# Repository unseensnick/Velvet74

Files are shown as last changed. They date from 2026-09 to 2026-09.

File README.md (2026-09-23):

# Velvet74

A 74-key split keyboard with Choc switches and a chip-down RP2040 on each half, in the Sofle layout. Key positions,
the board outline and the case come from [Ergogen](https://github.com/ergogen/ergogen); parts, nets and
fabrication data live in a KiCad 10 project aimed at JLCPCB assembly.

## The board

One 4-layer board, 268 x 118 mm before the panel rails, holds both halves 10 mm apart. Each half has 37 keys: a 6 x 5 matrix, 5 thumb
keys and 2 EC11 encoders that double as keys, each with an SK6812MINI-E under it.

- **Controller (per half):** RP2040, W25Q128JV 16 MB QSPI flash, 12 MHz ABM8-272-T3 crystal, AP2112K-3.3 LDO,
  BOOTSEL and RESET buttons.
- **USB-C host port:** 1.1 A polyfuse, B5819W reverse-current diode into +5V, SMF5.0A TVS on VBUS, USBLC6-2P6 on
  the data pair.
- **USB-C link port:** joins the halves (+5V, ground and a one-wire link on GP12), protected by its own USBLC6-2P6.
- **Display:** a 0.91" SSD1306 module on the 4-pin J3 header (I2C1).
- **Stackup:** signals on F.Cu and B.Cu, the +5V plane on In1 (with a +3.3V island under the controller), GND on
  In2. Power runs through the planes.
- **Panel:** the halves ship as one 268 x 131 mm panel. A 5 mm rail above and below carries the 2 mm tooling holes
  and three fiducials, and ten 5 mm tabs hold the halves, five per half, away from the USB-C cutouts. Mouse bites
  perforate each tab at the board edge: snap the tabs, then file the nubs flat. Nothing is left on the keyboard.

The schematic draws one half (`velvet74-half.kicad_sch`) and uses it twice, as sheets `Left` and `Right`.
Left references are plain (U1, SW10); right ones add 200 (U201, SW210). Both halves share one pin map.

## Pin map (both halves)

| Function | Pins |
| --- | --- |
| Rows 1-5, thumb row | GP5, GP4, GP3, GP2, GP1, GP0 |
| Columns outer to inner | GP29, GP28, GP27, GP26, GP25, GP24 |
| Encoder 1 (SW16) | A GP13, B GP14, key column GP20 |
| Encoder 2 (SW65) | A GP18, B GP19 |
| Display I2C1 | SDA GP6, SCL GP7 |
| RGB data | GP10, through the U6 level shifter to 5 V |
| Split link | GP12 |
| VBUS sense | GP9 (10k/10k divider) |
| Handedness jumper JP1 | GP8 (3.3 V = left, GND = right) |

37 LEDs at full white exceed the USB budget, so firmware should cap RGB brightness (around 120 of 255).

## Layout

- `velvet74.kicad_pro` / `.kicad_sch` / `.kicad_pcb` / `.kicad_dru`: the KiCad project, with the half sheet
  above.
- `lib/`: project symbols, footprints and 3D models (`my-soffle.*`), and the used JLCPCB library parts (`jlcpcb/`).
- `datasheets/`: manufacturer datasheets for every part on the board, synced from LCSC.
- `ergogen/`: the live layout (`config.yaml`). `npm run build` writes both halves' points, outline and case to
  `ergogen/output/`.
- `scripts/`: KiCad Python scripts that place parts from the Ergogen points and snap LEDs, diodes and caps to their
  switches.
- `templates/rp2040-inner-column/`: the RP2040 module the controller block started from, with its own README.
- `production/`: fabrication outputs, regenerated from the board before an order. `jlcpcb/` holds the
  Fabrication Toolkit set; `pcbway/` holds a `kicad-cli` set with a manufacturer-part-number BOM and assembly
  drawings. The two placement files use different rotation conventions, so do not mix them (see
  `production/pcbway/README.md`).

`CLAUDE.md` has the detailed file map, the rules for editing the design safely, and the checks.

## Getting started

**To open, review or edit the design** you need only [KiCad 10](https://www.kicad.org/download/) (made with
10.0.3); open `velvet74.kicad_pro`. Every library part the design uses is in the repo: the project's own parts
in `lib/my-soffle.*`, and the JLCPCB parts it uses in `lib/jlcpcb/` (copied from the JLCPCB library, MIT). The
remaining parts and 3D models are KiCad's stock ones. No Plugin and Content Manager packages, environment variables
or library setup are needed, and the 3D viewer shows every part. KiCad 8 cannot open these files; tag
`kicad8-final` is the last KiCad 8 state.

**To regenerate the layout** (key positions, outline, case): [Node.js](https://nodejs.org/) 18 or newer (Ergogen's `mathjs` dependency
requires it), then

```bash
cd ergogen && npm install && npm run build
```

Ergogen 4.2.1 is pinned in `ergogen/package.json`; the output lands in `ergogen/output/`.

**To run the scripts in `scripts/`:** KiCad's bundled Python (`<KiCad>/10.0/bin/python.exe` on Windows), with KiCad
closed. Each script's docstring says how to run it and what it overwrites.

**To regenerate `production/jlcpcb/`:** the Fabrication Toolkit plugin (from the KiCad Plugin and Content
Manager), with its automatic translation left **off**. JLCPCB's zero degrees is the part's orientation in its own
LCSC package drawing, which differs from KiCad's for some packages, so each affected part carries an
`FT Rotation Offset` or `FT Position Offset` field checked against JLC's own footprint. The plugin's name-matching
rules would rotate parts that are already right.

**To regenerate `production/pcbway/`:** `scripts/export_pcbway.py`, which drives `kicad-cli` and then writes the
placement file and an MPN-keyed BOM. Those offset fields are JLCPCB's and must not be applied here, so the
placement file keeps KiCad's own angles; the only correction is moving the four USB-C rows onto the part centroid.

**To commit:** activate the tracked commit-message hook once per clone with `git config core.hooksPath .githooks`
(see `CLAUDE.md` for the message format).

## Checks

```bash
kicad-cli sch erc --severity-error --exit-code-violations velvet74.kicad_sch
kicad-cli pcb drc --schematic-parity --severity-error --exit-code-violations velvet74.kicad_pcb
```

Expected: ERC has no errors. DRC has 26 known `courtyards_overlap` errors (mounting holes H1-H5 against their
neighbouring switches, 13 per half) and no unconnected items or parity issues. With all severities shown there are
also known warnings: 24 ERC `pin_to_pin` warnings and 3 `lib_symbol_mismatch` (J201, J202 and JP201 differ from their
library copies), and DRC silkscreen and `lib_footprint_mismatch` warnings for parts edited on the board.

## License

The design files, scripts and documentation are released under the MIT license (see `LICENSE`): you may use,
modify, build and sell them as long as the copyright notice is kept. The design comes with no warranty; check it
yourself before ordering boards.

Credits and third-party parts:

- The layout follows the [Sofle keyboard](https://github.com/josefadamcik/SofleKeyboard) by Josef Adamcik
  (MIT, (c) 2019 Josef Adamcik).
- `lib/jlcpcb/` holds parts of [CDFER/JLCPCB-Kicad-Library](https://github.com/CDFER/JLCPCB-Kicad-Library)
  (MIT, (c) 2024 Chris Dirks, license in `lib/jlcpcb/LICENSE`).
- `lib/my-soffle.3dshapes/SW_Hotswap_Kailh_Choc_V1.wrl` and the Choc hotswap footprints derive from
  [kiswitch/keyswitch-kicad-library](https://github.com/kiswitch/keyswitch-kicad-library) (MIT and CC-BY-SA 4.0).
- `datasheets/` holds the manufacturers' datasheets. They are the manufacturers' copyright, included for reference
  only, and are not covered by this project's license.

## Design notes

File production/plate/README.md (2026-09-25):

# FR4 top plate

`velvet74-plate.zip`: gerbers and drill for both halves' top plates on one panel, the same 268 x 133.25 mm rails,
tabs, mouse bites and tooling holes as the PCB panel. Built by `scripts/export_plate.py` from Ergogen's
`plate_outline`; rebuild with `npm run build` in `ergogen/`, then that script.

Order settings: FR4, 2 layers (no copper is drawn), **0.8 mm thick**, any solder mask colour. Nothing is assembled.

- Switch cutouts are 14.0 mm, so Choc v1 (13.80 mm body) and v2 (13.95 mm) both fit. The plate is a cover: at
  0.8 mm the switch clips do not grip it (they take 1.30 mm on v1, 1.65 mm on v2), so the hotswap sockets hold the
  switches, and the rims sit 0.2 mm above their natural seat on the 1.6 mm spacer.
- Five 2.2 mm M2 holes per half, on the PCB's H1-H5 and the case pillars. Meant for M2 x 6 wafer-head screws
  (3.8-4.1 mm head) into heat-set inserts; at H2 and left H3 a head reaches up to about 0.35 mm under the
  neighbouring switch rims; if one sits high, notch its rim edge or leave that screw out.
- The screen opening is 10.0 x 28.5 mm and overlaps the OLED glass by 0.75 mm all round.

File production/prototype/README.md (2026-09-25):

# Prototype print set (left half)

STLs for test-printing the left half's stack before ordering boards. All files share Ergogen's x/y frame, so
importing them together without moving them puts every part in place.

| File | Part | Print |
| --- | --- | --- |
| `velvet74-left-1-case.stl` | Case: 2.05 mm floor, pillars with blind 3.2 mm holes for CNC Kitchen M2 x 3.0 heat-set inserts, closed USB-C slots, SIM-pin holes under BOOT and RESET, 1 mm rounded top and bottom outer edges | open side up |
| `velvet74-left-2-pcb-dummy.stl` | PCB stand-in cut from the real board: every hole, LED window and USB-C slot, plus the back-side hotswap sockets, USB-C bodies and reset/boot buttons | already flipped, top face on the bed |
| `velvet74-left-3-spacer.stl` | 1.6 mm spacer between PCB and plate, 14.7 mm switch openings that clear the Choc clip hooks | flat |
| `velvet74-left-4-plate.stl` | 0.8 mm top plate (FR4 in the real build), 14.0 mm switch cutouts that take Choc v1 and v2 | flat, 0.2 mm layers |
| `velvet74-left-5-oled-standin.stl` | 0.91" OLED module (12 x 38 mm board plus glass), lies over J3 | flat |
| `velvet74-left-6-encoder-standins.stl` | EC11 body, bushing and 20 mm shaft at SW16 and SW65 (typical EC11 sizes, not a datasheet) | upright |
| `velvet74-left-7-keebart-fit-gauge.stl` | 1.2 mm frame with a 15.4 mm window per switch that Keebart's board shares; with the caps off it drops flush over the Keebart's switches if our positions match | flat |

Stack heights above the case bottom: PCB underside 4.25, spacer 5.85, plate 7.45, top 8.25.

The case, spacer and plate are Ergogen's own `ergogen/output/cases/` parts, unchanged: the case's USB-C ports are
closed 9.0 x 3.2 mm slots with a chamfer stepped in three. They were converted with manifold-3d instead of JSCAD's CSG,
which leaves T-junctions in the mesh.

The PCB dummy is KiCad's board-only STL of the left half plus blocks for the back-side parts; the stand-ins and the
gauge are drawn from the board's footprint positions. All of it was made with scratch tools outside the repo.

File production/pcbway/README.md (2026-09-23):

# PCBWay production files

Velvet74, one panel holding both halves. Regenerate the whole folder with
`scripts/export_pcbway.py velvet74.kicad_pcb`, which drives KiCad 10.0.3's own `kicad-cli`
rather than the Fabrication Toolkit plugin, because that plugin writes JLCPCB's conventions.

| File | What it is |
| --- | --- |
| `gerbers.zip` | 11 gerber layers, separate PTH and NPTH Excellon drill files, and drill maps |
| `positions.csv` | 312 placements, all bottom side |
| `bom.csv` | 23 lines keyed by manufacturer part number, PCBWay's turnkey columns |
| `assembly-top.pdf`, `assembly-bottom.pdf` | Fabrication-layer drawings with pad outlines and numbers |

## Read this before uploading

**The rotation convention differs from the JLCPCB set, on purpose.** `positions.csv` holds KiCad's
native angles: for a bottom-side part the angle is in the footprint's own frame, not mirrored into
a top view. JLCPCB wants the mirrored angle plus a per-part correction for its own library, which
is what `../jlcpcb/positions.csv` contains and why the two files disagree (U3 reads 180 here and 0
there). **Do not mix the two files.** PCBWay publishes no rotation convention of its own and their
guidance is to confirm orientation from assembly drawings, which is why both are included here.
Ask them to confirm against `assembly-bottom.pdf` before the run.

**The four USB-C rows sit on the part centroid**, not on the footprint anchor. Our mid-mount
footprint anchors at the connector mouth, 3.945 mm from the centre of the pad field, so
`kicad-cli`'s raw output would have placed all four connectors 3.945 mm out. Every other part's
anchor already is its centroid.

## Parts

Four lines had no MPN on the board and were filled from the value, description and datasheet in
the repo: RP2040 (Raspberry Pi), SK6812MINI-E (OPSCO Optoelectronics), SN74LV1T34DBVR (Texas
Instruments) and HC-TYPE-C-16P-C16B (HongCheng). Worth a second look if PCBWay queries them.

The passives, the 1N4148W and the SOD-123 Schottky are generic: any equivalent part in the same
package is fine, and naming a manufacturer there is only a starting point for sourcing. The parts
that are not interchangeable are the RP2040, the ZD25Q128C flash, the AP2112K, the SN74LV1T34, the
ABM8-272-T3 crystal, the USBLC6-2P6 and the SK6812MINI-E.

**Not in this BOM, and not assembled by anyone:** 74 Kailh Choc hotswap sockets, two 1x04 OLED
headers and two solder jumpers per keyboard. Those are hand soldering. The Choc switches, keycaps,
EC11 encoders and OLED modules are separate purchases too.

## Ordering notes

- PCBWay's assembly minimum is **5 boards**, where JLCPCB's is 2, so the option of proving two
  first does not exist here.
- Assembly is quoted by a person, typically 1 to 2 business days after upload, rather than priced
  instantly.
- The panel is 268 x 131 mm on 5 mm breakaway rails with mouse-bitten tabs. Tell them it is a
  customer panel and must not be re-panelised.
- Board is 4 layers, 1.6 mm, all 312 placements on the bottom side.

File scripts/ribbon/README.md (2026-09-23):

# Ribbon router

Experimental router for the Reddit-style look: traces run as octilinear lanes parallel to each key's keepout outline, so later traces bundle beside earlier ones. None of these scripts write the project board; `apply.py` writes a copy.

Pipeline (KiCad 10 Python for pcbnew steps, `uv run --no-project --with shapely` for the rest):

1. `extract.py board.kicad_pcb board.json`: pads, board outline and cutouts.
2. `channels.py board.json map`: optional channel-map renders per layer.
3. `make_links.py board.json links.json [NET ...]`: matrix links (switch to diode, rows and columns as MST, LED data chain).
4. `ribbon.py board.json links.json routes.json [prior_routes.json]`: routes links in order; prior routes stay fixed. `WINDOW` env widens the search box (default 6 mm).
5. `apply.py in.kicad_pcb routes.json out.kicad_pcb`: writes tracks and vias onto a copy, restores the `.kicad_pro`.
6. `dump_board.py` and `render_crop.py`: PNG review renders.

Rules baked in: 0.2 mm tracks at 0.4 mm pitch, 0.6/0.3 mm vias, clearances 0.205 copper / 0.36 hole / 0.5 edge mm (small margins over the JLCPCB-recommended rules because pads are polygonised; 0.13 inside the U1, J1, J2, U2 and U4 courtyards, matching `velvet74.kicad_dru`), no turn sharper than 90 degrees including through a via.

Status: the 2-layer key matrix routes completely (136 links, 124 vias, DRC 0 clearance errors on a scratch copy). Power, controller area and U1-to-matrix bundles are not done.

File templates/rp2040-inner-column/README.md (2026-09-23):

# RP2040 Inner Column Module

A KiCad 10 template for a chip-down RP2040 controller that lives on the back of a Choc split keyboard,
in the strip beside the inner key column, the way the Keebart Sofle Choc Pro does it. The layout
follows the ScottoModules idea: copy the schematic and board into a keyboard project, then wire the
GPIO labels to the matrix.

The circuit is the controller half of the audited `velvet74.kicad_sch` in the repo root, so
reference designators and LCSC part numbers match the keyboard.

## Board

- No Edge.Cuts: the modules are pasted into an existing keyboard board, which brings its own outline.
- Two groups, like ScottoModules, each moving as one unit on the host board:
  - **USB and power**: J1, U4, R5, R6, F1, D1, U5, C9, C18, C19, C20
  - **RP2040**: U1, the flash U3 with C3, the crystal X1 with C1, C4 and R2, the USB series resistors
    R7 and R8, all RP2040 decoupling caps, BOOT/RESET (SW1, SW2, R4) and the JLC marker
- As placed, the two groups fill a 19.56 x 41.6 mm strip measured from the free space on the Sofle
  board, whose top and right are real board edges; the left and bottom meet the key area. That
  arrangement is the one the routability check below covers. Pull the groups apart only if the host
  board needs it, and leave room for the traces between them.
- Every part is on the back (B.Cu) for single-sided JLCPCB assembly.
- The RP2040 sits at 45 degrees. USB pins point at the USB-C connector on the top edge, QSPI pins at
  the flash (also at 45 degrees) up and to the right, GP18-29 and GP12-17 fan out to the left and
  bottom-left, and GP0-11 run straight down to the bottom edge. BOOT/RESET are along the bottom edge
  and the regulator group sits beside the USB-C shell.
- Routing room is built in: pads of different parts are at least 0.6 mm apart (mostly 0.8 mm), and
  other parts keep 1.6 mm off the RP2040 pins for fanout and vias.
- The price of that room: decoupling caps are 2.4 to 6.7 mm from their pins (3.9 mm on average), the
  crystal is 2.9 mm from XIN, the 27 ohm USB resistors are within 3.7 mm, and the longest flash line
  (SS) is about 15 mm.
- Silkscreen holds only the footprint outlines and a `JLCJLCJLCJLC` marker, which JLCPCB replaces with
  the order number. Reference designators are on B.Fab.
- **Routed** on 2 layers: most signals on B.Cu with the parts, a GND pour on F.Cu. Design rules are
  JLCPCB's standard 2-layer floor, which the routing needs: 0.127 mm clearance and track, 0.45/0.2 mm
  vias, 0.2 mm hole to hole. Net classes still set the default widths (Power5V 0.5 mm, Power3.3V
  0.3 mm, USB 0.2 mm); tracks neck down near the fine-pitch pins.
- Every GPIO (GP0-29) is routed out from the RP2040 and ends on the strip's left or bottom edge, ready
  to continue into the key area on the host board.
- Three internal nets briefly leave the strip on the left or bottom: +3.3V (up to 2.2 mm), RUN
  (2.2 mm) and +1V1 (0.7 mm). Keep that margin free of copper on the host board, or reroute them.

## Checks

```bash
kicad-cli pcb drc --schematic-parity --severity-error RP2040InnerColumn.kicad_pcb
```

Routed (KiCad 10.0.3): 0 schematic parity issues, 0 footprint field mismatches, no clearance,
courtyard, via or hole errors. Expected items:

- `invalid_outline`: the template has no Edge.Cuts on purpose; it goes away inside the host board.
- 30 `track_dangling` warnings: the GPIO traces end at the strip edge until the host board continues
  them.
- 1 `track_dangling` warning on +3.3V at (67.05, 58.9): that track ends on the middle of another +3.3V
  track, which KiCad flags although the copper is connected.
- 1 unconnected GND item between the GND pads of C13 and C14: that piece of the F.Cu pour is closed in
  by GPIO traces and joined the rest of the GND pour only through the key area. It rejoins once the
  host board's GND pour continues past the strip edge; standalone, it needs a GND via or track.

KiCad 8 also reported two hole clearance errors inside the USB-C footprint (C2927039,
`TYPE-C-SMD_HX-TYPE-C-16PIN`, GND pads 0.204 mm from the NPTH peg holes against a 0.25 mm rule);
KiCad 10 no longer reports them.

## Routability

The placement was chosen by autorouting many variants (RP2040 straight or at 45 degrees, positions,
flash and USB resistor placement, spacing) with Freerouting, on a copy of the board with every GPIO
forced out to a pad in a 3 mm strip on the left and bottom edges, where the key area continues.
This placement was the only one that routed completely on 2 layers. The autorouted copy was
imported back into KiCad and checked there at 0.15 mm clearance: every signal and power net
connected with no clearance errors. With GND pours on both layers and stitching vias, all GND pads
joined except the GND pads of C6 and C11, where the autorouter's traces left no room for a via.
When routing by hand, drop a GND via beside each decoupling cap before routing the signals.

The routing itself was done with KiCad Routing Tools (QFN fanout, GND pour, then every net) on the
same test board, finished by hand in KiCad 10, and copied onto the template with
`scripts/transfer_module_routing.py`, which cuts each GPIO at the strip edge and drops the test pads.

## Rebuilding the placement

`scripts/build_rp2040_module.py` generates the board from the schematic netlist. It overwrites the
board file, **routing included**, so running it now discards the routing:

```bash
kicad-cli sch export netlist -o module.net templates/rp2040-inner-column/RP2040InnerColumn.kicad_sch
```

```bash
"%LOCALAPPDATA%/Programs/KiCad/10.0/bin/python.exe" scripts/build_rp2040_module.py module.net
```

## Bill of materials

| References | Qty | Value | Footprint | LCSC |
| --- | --- | --- | --- | --- |
| C1, C4 | 2 | 15pF | C_0402 | [C1548](https://jlcpcb.com/partdetail/C1548) |
| C3, C5, C6, C10, C11, C12, C13, C14, C15, C16, C17 | 11 | 100nF | C_0402 | [C1525](https://jlcpcb.com/partdetail/C1525) |
| C7, C8, C19, C20 | 4 | 1uF | C_0402 | [C52923](https://jlcpcb.com/partdetail/C52923) |
| C9, C18 | 2 | 10uF | C_0603 | [C19702](https://jlcpcb.com/partdetail/C19702) |
| D1 | 1 | B5819W SL | D_SOD-123 | [C8598](https://jlcpcb.com/partdetail/C8598) |
| F1 | 1 | 500mA | Fuse_1206_3216Metric | [C163512](https://jlcpcb.com/partdetail/C163512) |
| J1 | 1 | USB-C 16P | TYPE-C-SMD_HX-TYPE-C-16PIN | [C2927039](https://jlcpcb.com/partdetail/C2927039) |
| R2, R4 | 2 | 1k | R_0402 | [C11702](https://jlcpcb.com/partdetail/C11702) |
| R5, R6 | 2 | 5.1k | R_0402 | [C25905](https://jlcpcb.com/partdetail/C25905) |
| R7, R8 | 2 | 27 | R_0402 | [C25100](https://jlcpcb.com/partdetail/C25100) |
| SW1, SW2 | 2 | BOOT, RESET | SW_Push_1P1T_XKB_TS-1187A | [C318884](https://jlcpcb.com/partdetail/C318884) |
| U1 | 1 | RP2040 | QFN-56-1EP_7x7mm_P0.4mm | [C2040](https://jlcpcb.com/partdetail/C2040) |
| U3 | 1 | W25Q128 | SOIC-8 5.3 mm | [C97521](https://jlcpcb.com/partdetail/C97521) |
| U4 | 1 | SRV05-4 | SOT-23-6 | [C2836319](https://jlcpcb.com/partdetail/C2836319) |
| U5 | 1 | AP2112K-3.3 | SOT-23-5 | [C51118](https://jlcpcb.com/partdetail/C51118) |
| X1 | 1 | ABM8-272-T3 | Crystal SMD 3.2 x 2.5 | [C20625731](https://jlcpcb.com/partdetail/C20625731) |

## Libraries

- `PCM_JLCPCB` (CDFER JLCPCB-Kicad-Library, installed through the KiCad Plugin and Content Manager)
- `rp2040_module`, bundled in `lib/`: the TS-1187A button footprint and its 3D model

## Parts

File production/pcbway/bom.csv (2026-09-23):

Line# | Qty | Designator | MPN | Manufacturer | Description | Package | Type
1 | 98 | C3,C5,C6,C10,C11,C12,C13,C14,C15,C16,C17,C30,C110,C111,C112,C113,C114,C115,C116,C120,C121,C122,C123,C124,C125,C130,C131,C132,C133,C134,C135,C140,C141,C142,C143,C144,C145,C150,C151,C152,C153,C154,C155,C160,C161,C162,C163,C164,C165,C203,C205,C206,C210,C211,C212,C213,C214,C215,C216,C217,C230,C310,C311,C312,C313,C314,C315,C316,C320,C321,C322,C323,C324,C325,C330,C331,C332,C333,C334,C335,C340,C341,C342,C343,C344,C345,C350,C351,C352,C353,C354,C355,C360,C361,C362,C363,C364,C365 | CL05B104KO5NNNC | Samsung Electro-Mechanics | 16V 100nF X7R ±10% 0402 Multilayer Ceramic Capacitors MLCC - SMD/SMT ROHS | 0402 | SMD
2 | 74 | D10,D11,D12,D13,D14,D15,D16,D20,D21,D22,D23,D24,D25,D30,D31,D32,D33,D34,D35,D40,D41,D42,D43,D44,D45,D50,D51,D52,D53,D54,D55,D60,D61,D62,D63,D64,D65,D210,D211,D212,D213,D214,D215,D216,D220,D221,D222,D223,D224,D225,D230,D231,D232,D233,D234,D235,D240,D241,D242,D243,D244,D245,D250,D251,D252,D253,D254,D255,D260,D261,D262,D263,D264,D265 | 1N4148W | ST | 75V Independent Type 1V@50mA 4ns 150mA SOD-123 Switching Diodes ROHS | SOD-123 | SMD
3 | 74 | LED10,LED11,LED12,LED13,LED14,LED15,LED16,LED20,LED21,LED22,LED23,LED24,LED25,LED30,LED31,LED32,LED33,LED34,LED35,LED40,LED41,LED42,LED43,LED44,LED45,LED50,LED51,LED52,LED53,LED54,LED55,LED60,LED61,LED62,LED63,LED64,LED65,LED210,LED211,LED212,LED213,LED214,LED215,LED216,LED220,LED221,LED222,LED223,LED224,LED225,LED230,LED231,LED232,LED233,LED234,LED235,LED240,LED241,LED242,LED243,LED244,LED245,LED250,LED251,LED252,LED253,LED254,LED255,LED260,LED261,LED262,LED263,LED264,LED265 | SK6812MINI-E | OPSCO Optoelectronics | SK6812MINI-E | SK6812MINI-E 3.2x2.8mm | SMD
4 | 8 | C7,C8,C19,C20,C207,C208,C219,C220 | CL05A105KA5NQNC | Samsung Electro-Mechanics | 25V 1uF X5R ±10% 0402 Multilayer Ceramic Capacitors MLCC - SMD/SMT ROHS | 0402 | SMD
5 | 4 | C1,C4,C201,C204 | 0402CG150J500NT | FH | 50V 15pF C0G ±5% 0402 Multilayer Ceramic Capacitors MLCC - SMD/SMT ROHS | 0402 | SMD
6 | 4 | R2,R4,R202,R204 | 0402WGF1001TCE | UNI-ROYAL | 62.5mW Thick Film Resistors 50V ±100ppm/°C ±1% 1kΩ 0402 Chip Resistor - Surface Mount ROHS | 0402 | SMD
7 | 4 | R10,R11,R210,R211 | 0402WGF1002TCE | UNI-ROYAL | 62.5mW Thick Film Resistors 50V ±100ppm/°C ±1% 10kΩ 0402 Chip Resistor - Surface Mount ROHS | 0402 | SMD
8 | 4 | R7,R8,R207,R208 | 0402WGF270JTCE | UNI-ROYAL | 27Ω ±1% 62.5mW 0402 thick film resistor (USB series termination) | 0402 | SMD
9 | 4 | R5,R6,R205,R206 | 0402WGF5101TCE | UNI-ROYAL | 62.5mW Thick Film Resistors 50V ±100ppm/°C ±1% 5.1kΩ 0402 Chip Resistor - Surface Mount ROHS | 0402 | SMD
10 | 4 | F1,F2,F201,F202 | 1206L110THYR | Littelfuse | Resettable fuse, polymeric positive temperature coefficient | 1206 | SMD
11 | 4 | C9,C18,C209,C218 | CL10A106KP8NNNC | Samsung Electro-Mechanics | 10V 10uF X5R ±10% 0603 Multilayer Ceramic Capacitors MLCC - SMD/SMT ROHS | 0603 | SMD
12 | 4 | J1,J2,J201,J202 | HC-TYPE-C-16P-C16B | HongCheng | 3A 1 Horizontal attachment 16P Female -25℃~+85℃ Type-C SMD USB Connectors ROHS | USB-C 16P mid-mount | Hybrid
13 | 4 | SW1,SW2,SW201,SW202 | TS-1088-AR02016 | XUNPU | Push button switch, generic, two pins | SMD 4x3mm | SMD
14 | 4 | U2,U4,U202,U204 | USBLC6-2P6 | R+O | USB ESD protection, 2 data lines and VBUS, SOT-563 | SOT-563 | SMD
15 | 2 | R16,R216 | 0402WGF1200TCE | UNI-ROYAL | 62.5mW Thick Film Resistors 50V ±100ppm/°C ±1% 120Ω 0402 Chip Resistor - Surface Mount ROHS | 0402 | SMD
16 | 2 | R15,R215 | 0402WGF4700TCE | UNI-ROYAL | 62.5mW Thick Film Resistors 50V ±100ppm/°C ±1% 470Ω 0402 Chip Resistor - Surface Mount ROHS | 0402 | SMD
17 | 2 | X1,X201 | ABM8-272-T3 | Abracon LLC | 12MHz 10pF 50ohm crystal, RP2040 hardware design guide reference part | SMD 3.2x2.5mm | SMD
18 | 2 | U5,U205 | AP2112K-3.3TRG1 | Diodes Inc | AP2112K-3.3 | SOT-23-5 | SMD
19 | 2 | D1,D201 | B5819W SL | Changjiang Electronics Tech | 40V 600mV@1A 1A SOD-123 Schottky Diodes ROHS | SOD-123 | SMD
20 | 2 | U1,U201 | RP2040 | Raspberry Pi | A microcontroller by Raspberry Pi | QFN-56 7x7mm | SMD
21 | 2 | D2,D202 | SMF5.0A | hongjiacheng | 27.4A 7.3V 200W 6.4V Unidirectional 5V SOD-123FL ESD and Surge Protection (TVS/ESD) ROHS | SOD-123FL | SMD
22 | 2 | U6,U206 | SN74LV1T34DBVR | Texas Instruments | Single Buffer Gate, Low-Voltage CMOS | SOT-23-5 | SMD
23 | 2 | U3,U203 | ZD25Q128CWIGR | Zetta | 128Mbit WSON-8-EP(6x5) NOR FLASH ROHS | WSON-8 6x5mm | SMD

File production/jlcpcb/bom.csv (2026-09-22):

Designator | Footprint | Quantity | Value | LCSC Part #
C1, C201, C204, C4 | C_0402 | 4 | 15pF | C1548
C10, C11, C110, C111, C112, C113, C114, C115, C116, C12, C120, C121, C122, C123, C124, C125, C13, C130, C131, C132, C133, C134, C135, C14, C140, C141, C142, C143, C144, C145, C15, C150, C151, C152, C153, C154, C155, C16, C160, C161, C162, C163, C164, C165, C17, C203, C205, C206, C210, C211, C212, C213, C214, C215, C216, C217, C230, C3, C30, C310, C311, C312, C313, C314, C315, C316, C320, C321, C322, C323, C324, C325, C330, C331, C332, C333, C334, C335, C340, C341, C342, C343, C344, C345, C350, C351, C352, C353, C354, C355, C360, C361, C362, C363, C364, C365, C5, C6 | C_0402 | 98 | 100nF | C1525
C18, C209, C218, C9 | C_0603 | 4 | 10uF | C19702
C19, C20, C207, C208, C219, C220, C7, C8 | C_0402 | 8 | 1uF | C52923
D1, D201 | D_SOD-123 | 2 | B5819W SL | C8598
D10, D11, D12, D13, D14, D15, D16, D20, D21, D210, D211, D212, D213, D214, D215, D216, D22, D220, D221, D222, D223, D224, D225, D23, D230, D231, D232, D233, D234, D235, D24, D240, D241, D242, D243, D244, D245, D25, D250, D251, D252, D253, D254, D255, D260, D261, D262, D263, D264, D265, D30, D31, D32, D33, D34, D35, D40, D41, D42, D43, D44, D45, D50, D51, D52, D53, D54, D55, D60, D61, D62, D63, D64, D65 | D_SOD-123 | 74 | 1N4148W | C81598
D2, D202 | D_SOD-123FL | 2 | SMF5.0A | C19077497
F1, F2, F201, F202 | 1206 | 4 | 1.1A | C126818
J1, J2, J201, J202 | USB_C_Receptacle_HongCheng_HC-TYPE-C-16P_MidMount | 4 | Connector, USB-TYPE-C-16P | C19274022
LED10, LED11, LED12, LED13, LED14, LED15, LED16, LED20, LED21, LED210, LED211, LED212, LED213, LED214, LED215, LED216, LED22, LED220, LED221, LED222, LED223, LED224, LED225, LED23, LED230, LED231, LED232, LED233, LED234, LED235, LED24, LED240, LED241, LED242, LED243, LED244, LED245, LED25, LED250, LED251, LED252, LED253, LED254, LED255, LED260, LED261, LED262, LED263, LED264, LED265, LED30, LED31, LED32, LED33, LED34, LED35, LED40, LED41, LED42, LED43, LED44, LED45, LED50, LED51, LED52, LED53, LED54, LED55, LED60, LED61, LED62, LED63, LED64, LED65 | LED-SMD_4P-L3.2-W2.8-LS5.9_SK6812MINI-E | 74 | SK6812MINI-E | C5149201
R10, R11, R210, R211 | R_0402 | 4 | 10kΩ | C25744
R15, R215 | R_0402 | 2 | 470Ω | C25117
R16, R216 | R_0402 | 2 | 120Ω | C25079
R2, R202, R204, R4 | R_0402 | 4 | 1kΩ | C11702
R205, R206, R5, R6 | R_0402 | 4 | 5.1kΩ | C25905
R207, R208, R7, R8 | R_0402 | 4 | 27Ω | C25100
SW1, SW201 | SW_Push_1P1T_XUNPU_TS-1088-AR02016 | 2 | BOOT | C720477
SW2, SW202 | SW_Push_1P1T_XUNPU_TS-1088-AR02016 | 2 | RESET | C720477
U1, U201 | QFN-56-1EP_7x7mm_P0.4mm_EP3.2x3.2mm_ThermalVias | 2 | RP2040 | C2040
U2, U202, U204, U4 | SOT-563_USBLC6-2P6 | 4 | USBLC6-2P6 | C49451919
U203, U3 | WSON-8-1EP_6x5mm_P1.27mm_EP3.4x4mm | 2 | ZD25Q128CWIGR | C53959302
U205, U5 | SOT-23-5_L3.0-W1.7-P0.95-LS2.8-BL | 2 | AP2112K-3.3 | C51118
U206, U6 | SOT-23-5 | 2 | SN74LV1T34DBVR | C100024
X1, X201 | CRYSTAL-SMD_4P-L3.2-W2.5-BL | 2 | ABM8-272-T3 | C20625731

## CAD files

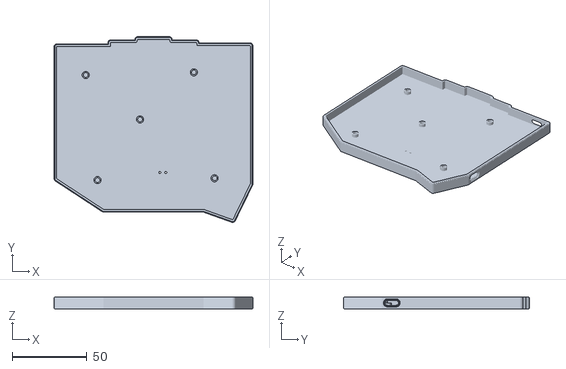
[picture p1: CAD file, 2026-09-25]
production/prototype/velvet74-left-1-case.stl
133.0 x 124.2 x 8.25

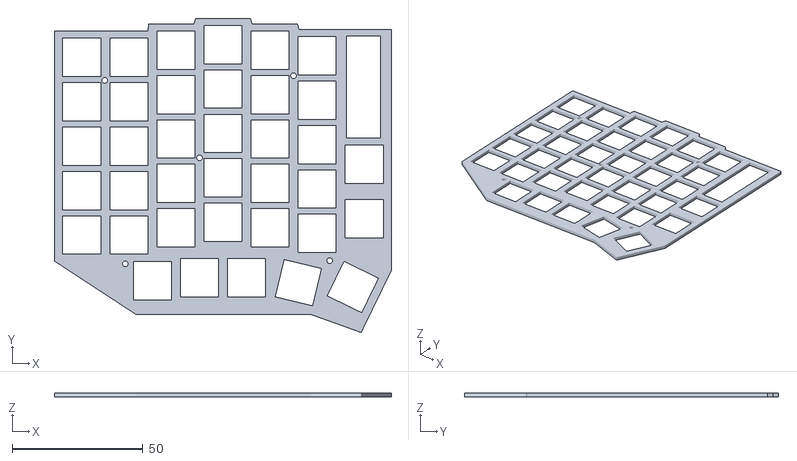
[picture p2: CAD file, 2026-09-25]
production/prototype/velvet74-left-3-spacer.stl
129.0 x 120.2 x 1.60

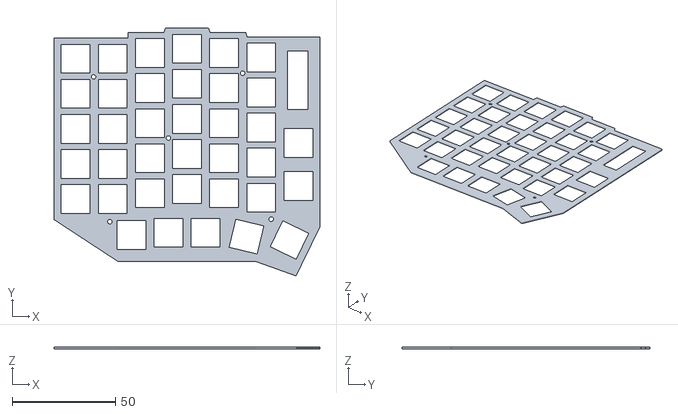
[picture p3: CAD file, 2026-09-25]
production/prototype/velvet74-left-4-plate.stl
129.0 x 120.2 x 0.8

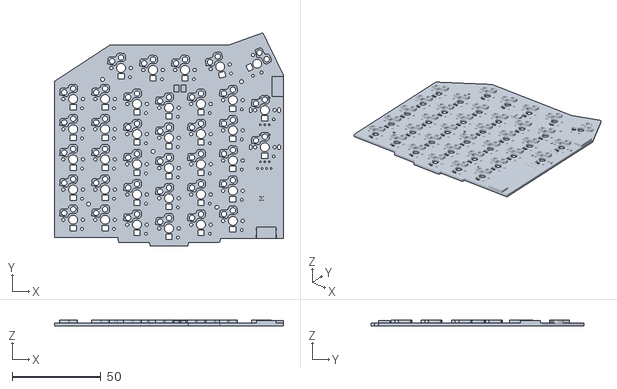
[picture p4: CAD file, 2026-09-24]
production/prototype/velvet74-left-2-pcb-dummy.stl
129.0 x 120.2 x 3.45

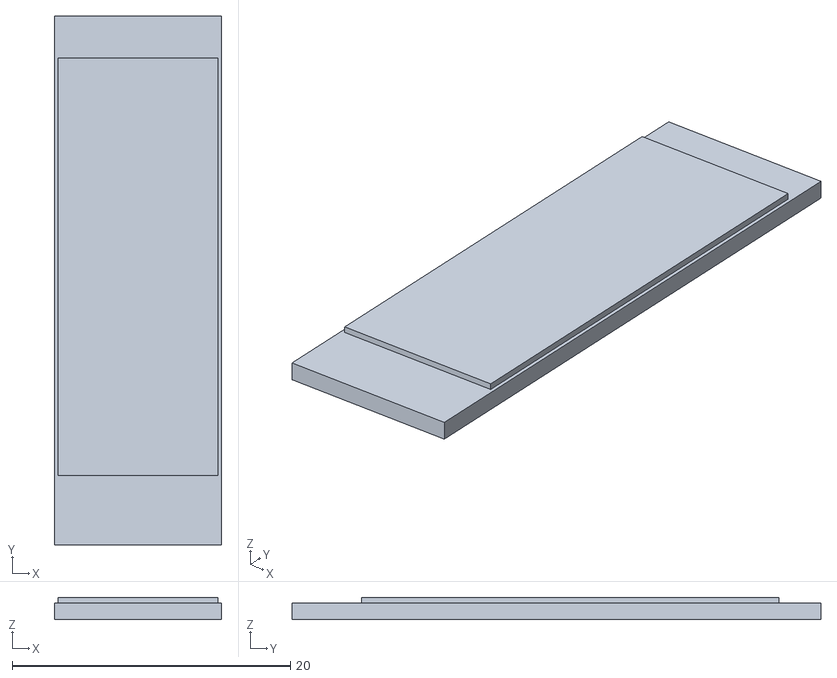
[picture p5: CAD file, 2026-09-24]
production/prototype/velvet74-left-5-oled-standin.stl
12.0 x 38.0 x 1.60

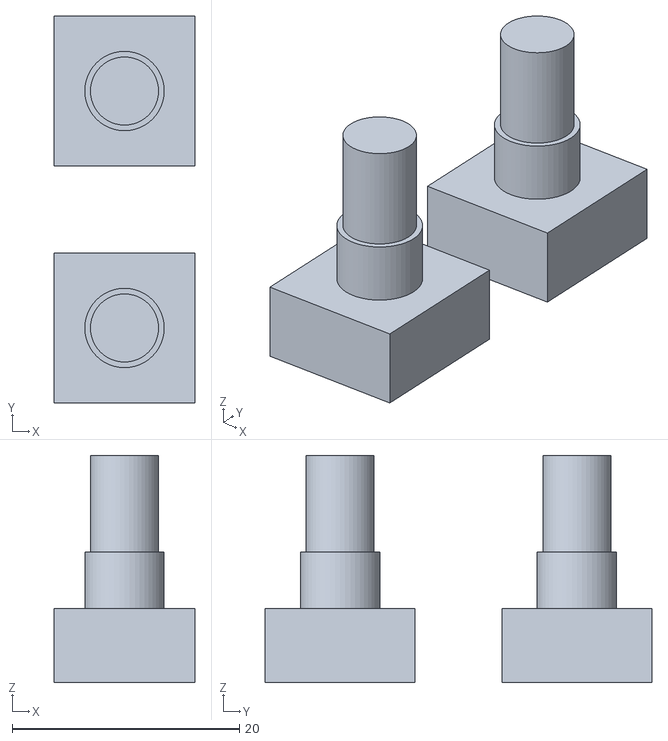
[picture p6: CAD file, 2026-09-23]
production/prototype/velvet74-left-6-encoder-standins.stl
12.4 x 34.1 x 20.0

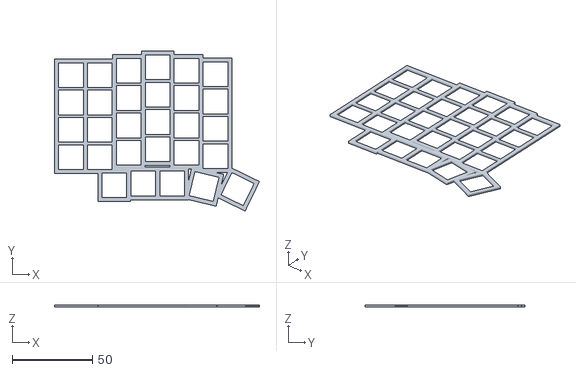
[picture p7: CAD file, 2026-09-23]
production/prototype/velvet74-left-7-keebart-fit-gauge.stl
127.5 x 99.6 x 1.20

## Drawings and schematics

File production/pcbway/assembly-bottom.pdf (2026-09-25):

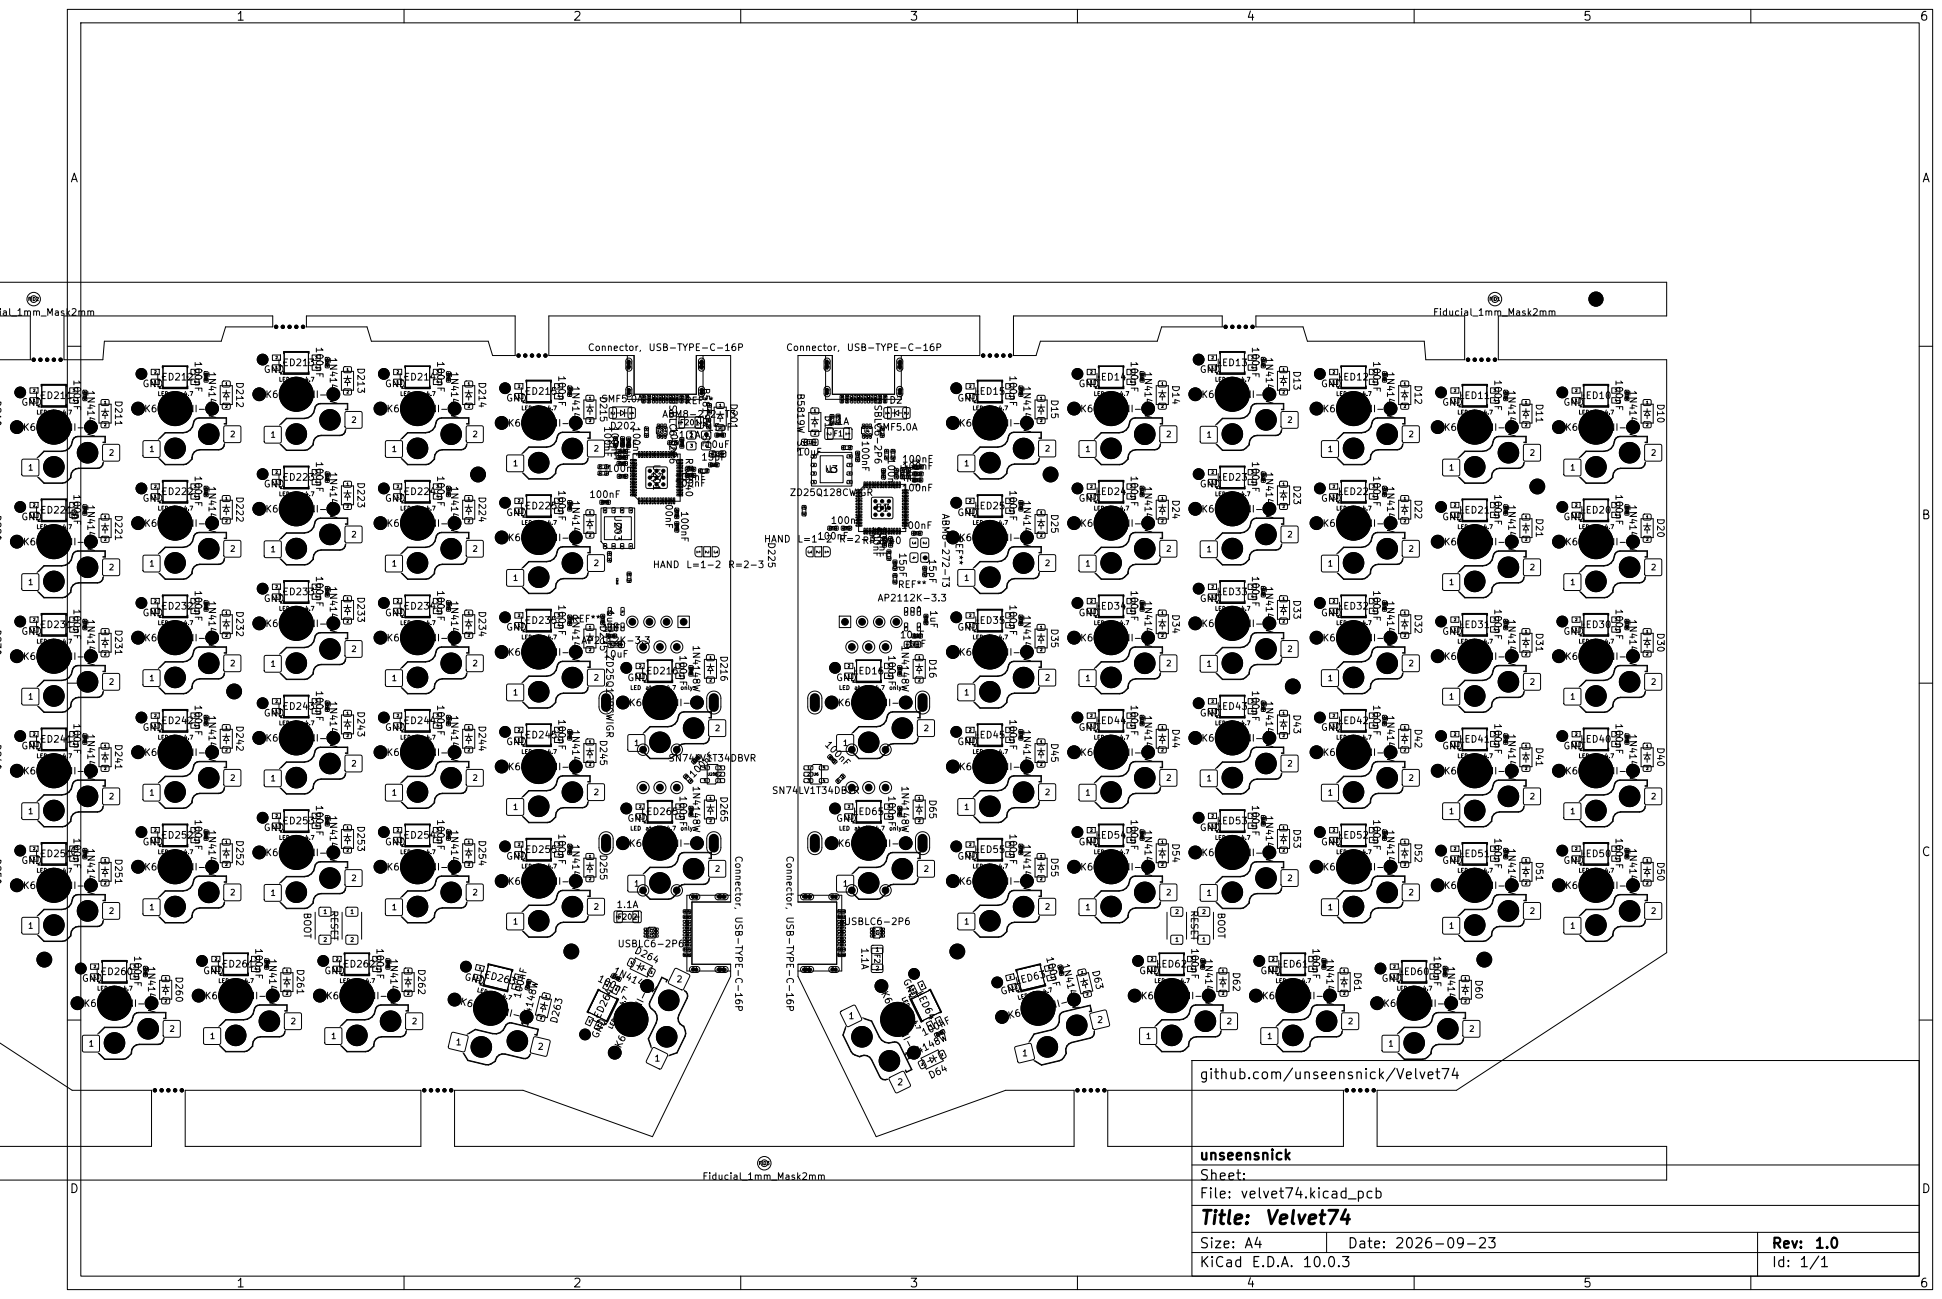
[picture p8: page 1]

LED22 GND Connector, USB-TYPE-C-16P

LED at 0,+4.7 only LED 0,+4.7
USBLC6-2P6 U202 SK6812MINI-E

Size: A4 | Rev: 1.0
KiCad E.D.A. 10.0.3 | Id: 1/1

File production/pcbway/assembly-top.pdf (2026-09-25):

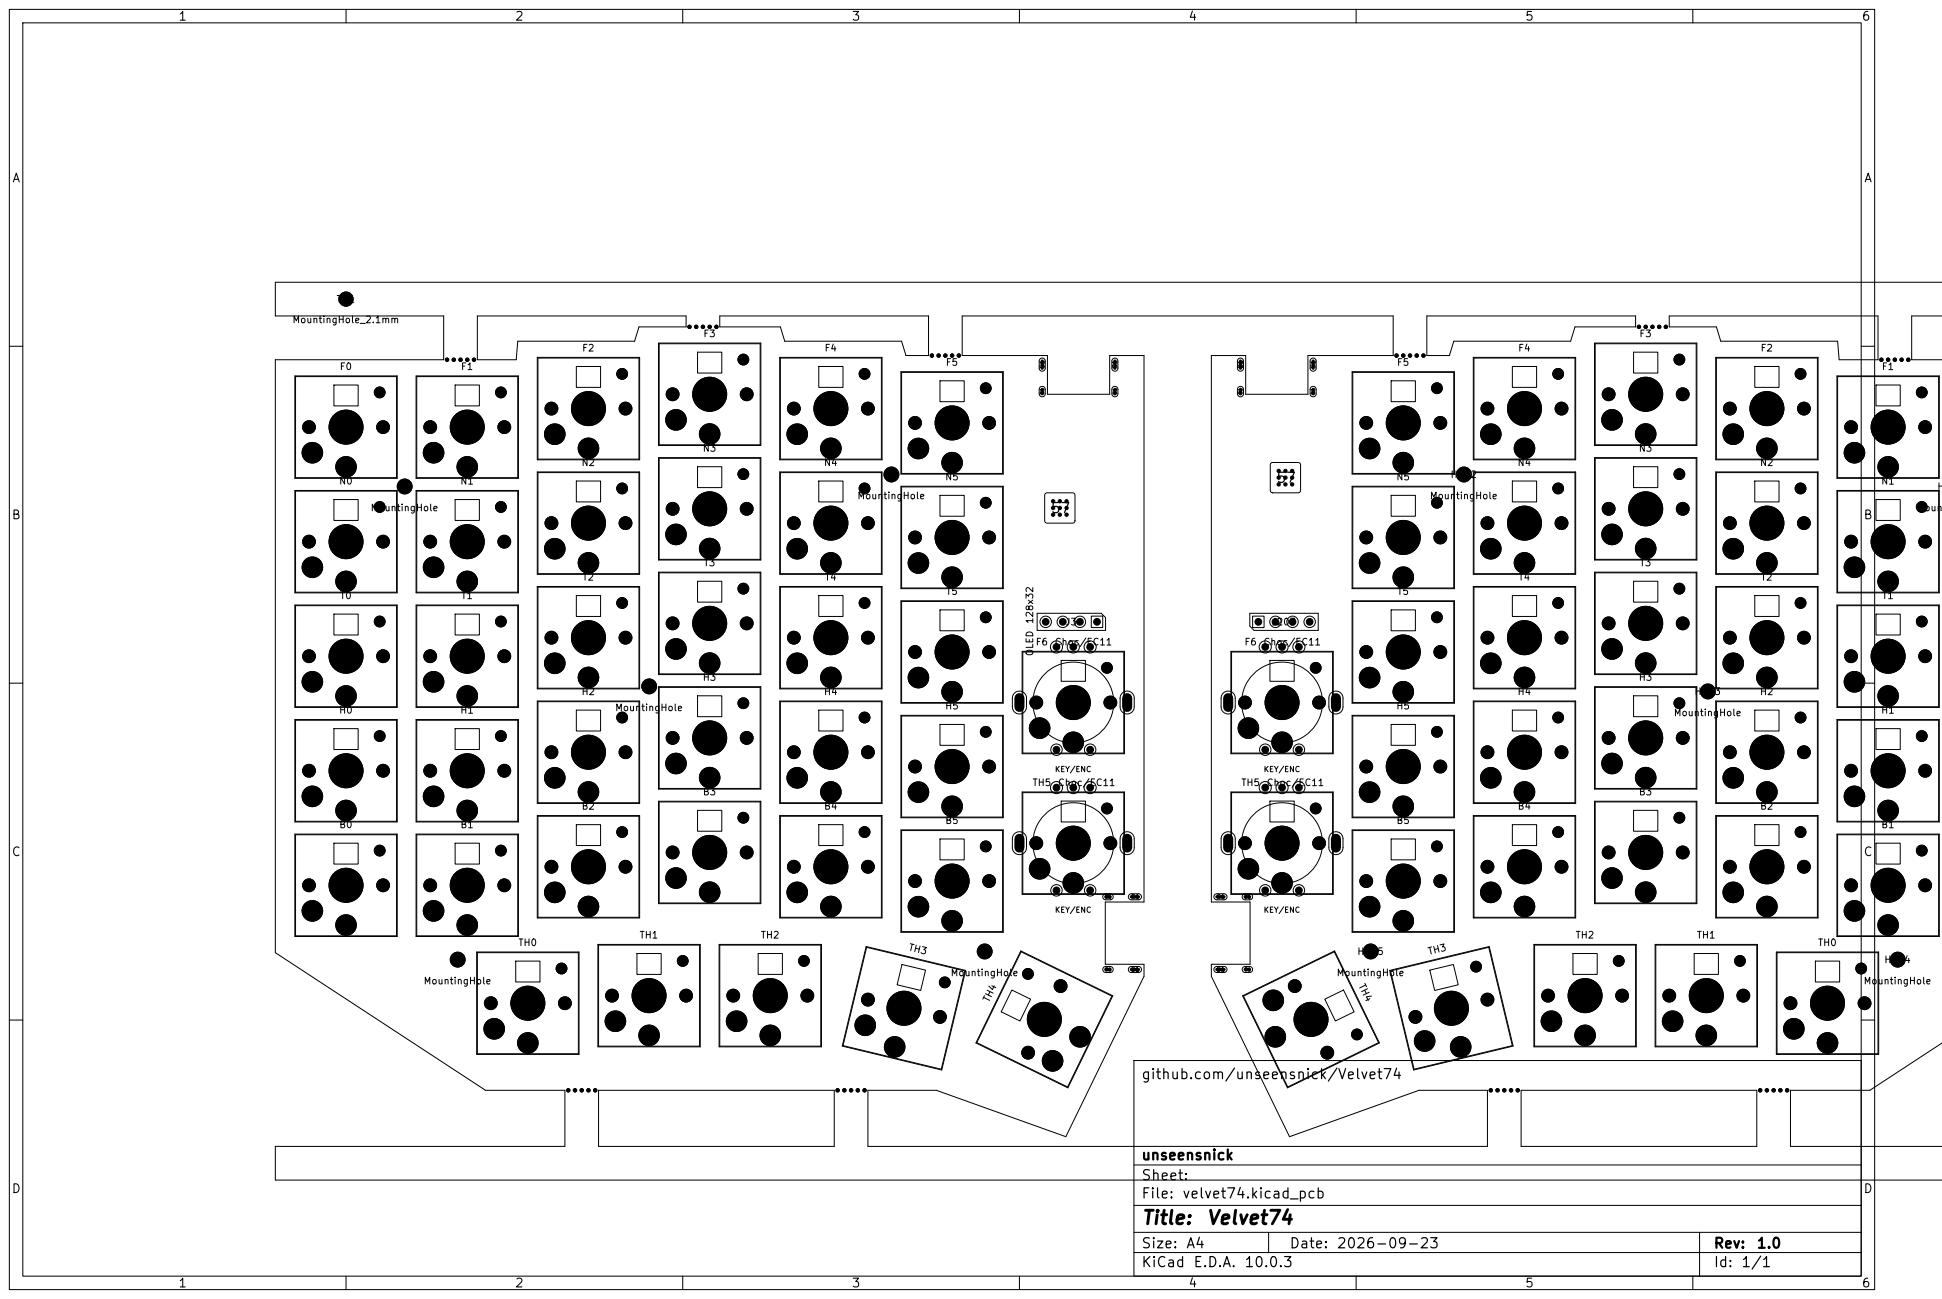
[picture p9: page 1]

Size: A4 | Rev: 1.0
KiCad E.D.A. 10.0.3 | Id: 1/1

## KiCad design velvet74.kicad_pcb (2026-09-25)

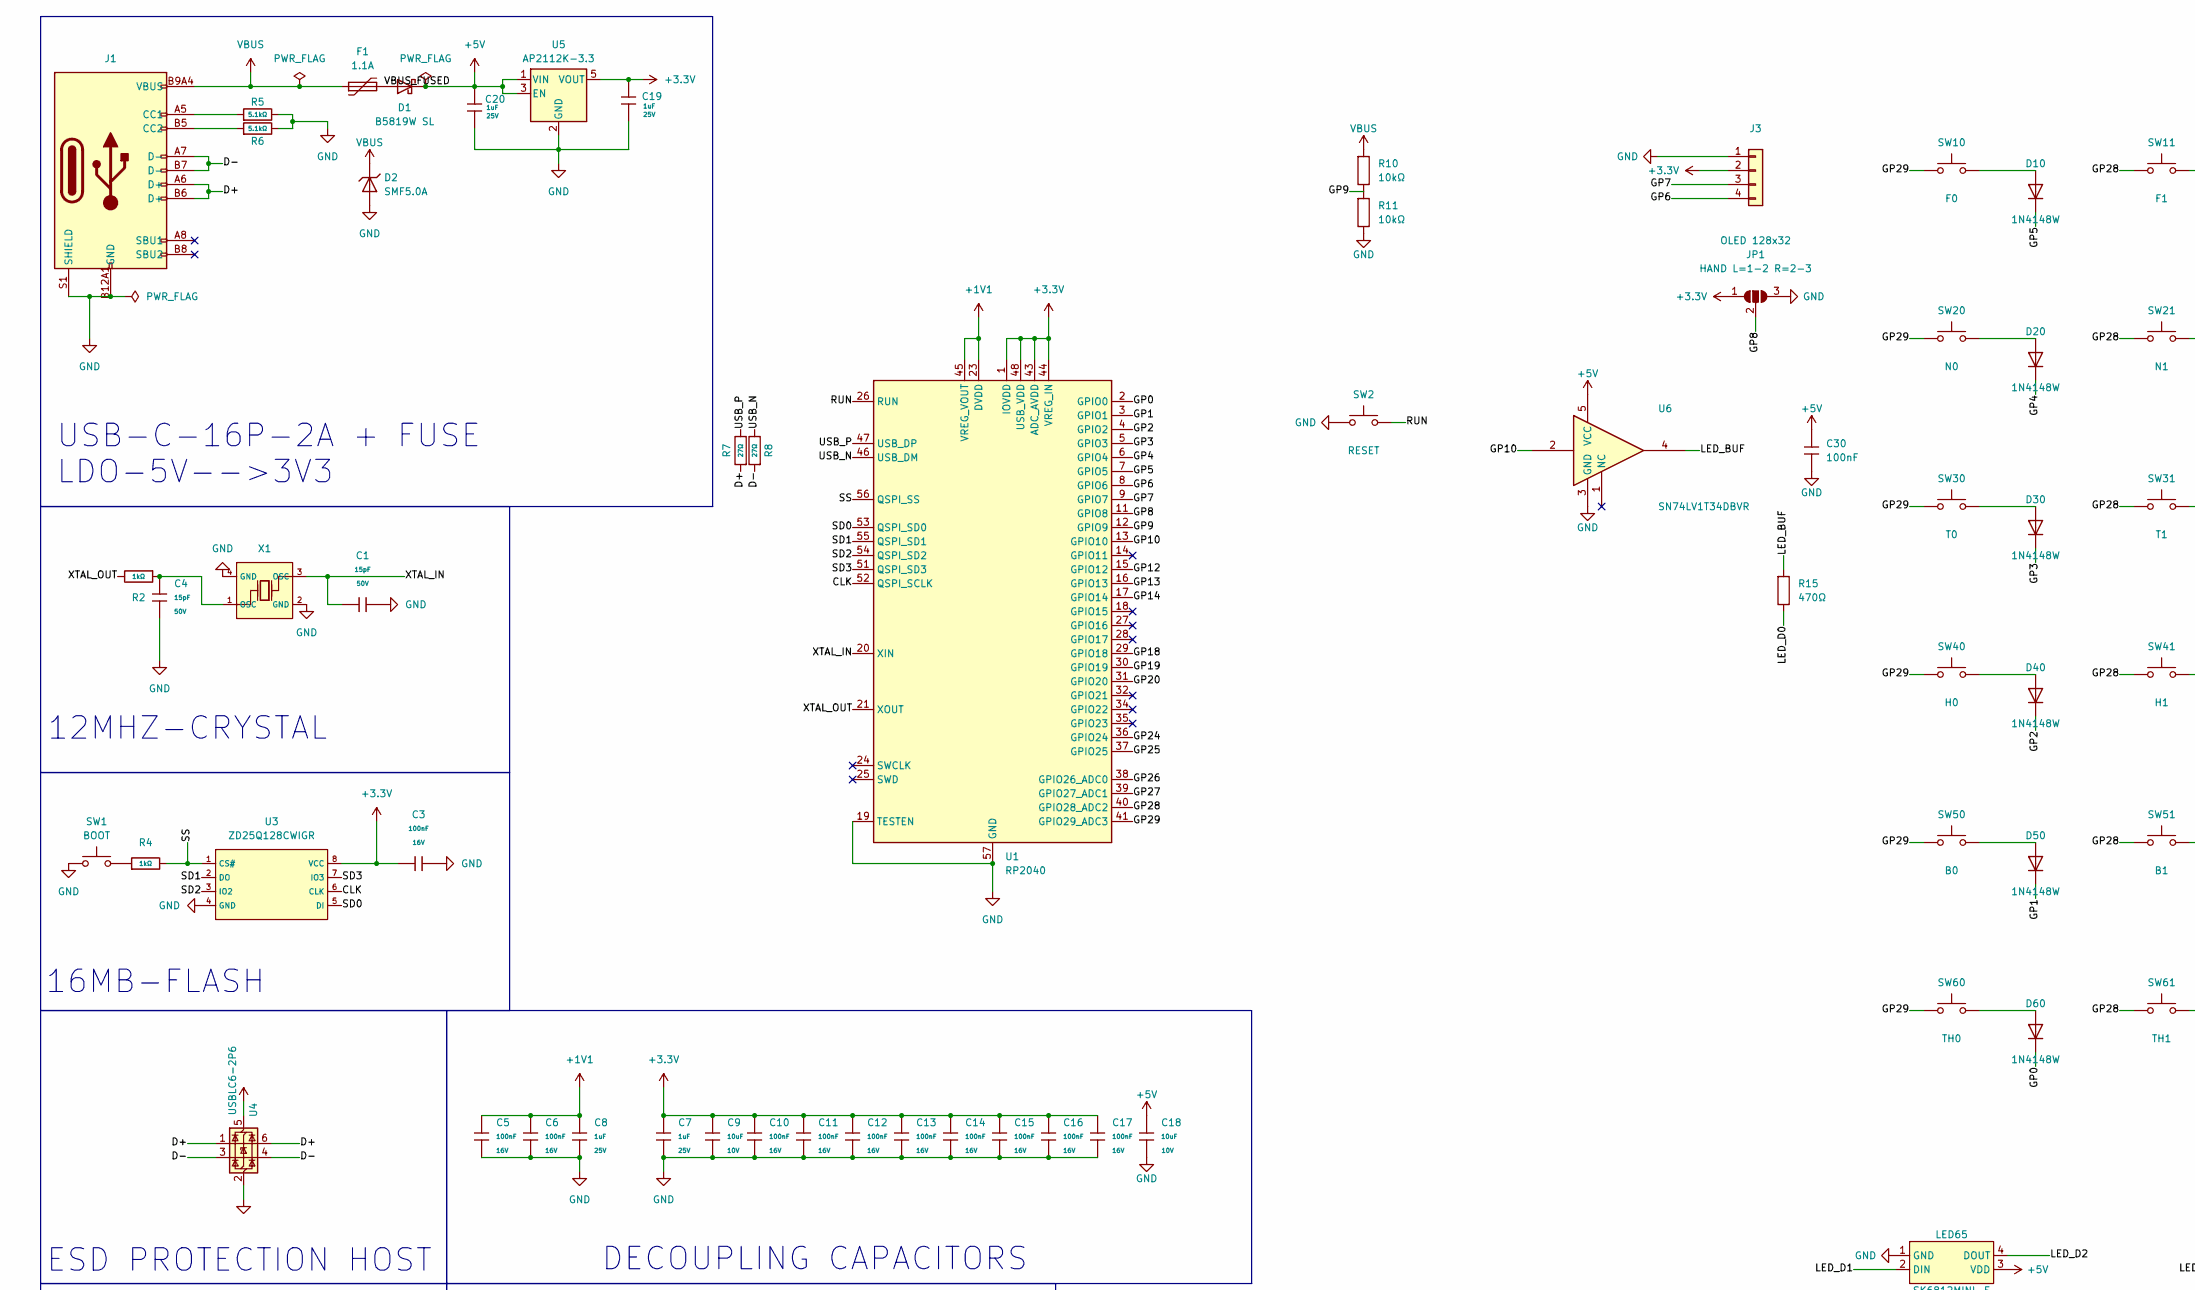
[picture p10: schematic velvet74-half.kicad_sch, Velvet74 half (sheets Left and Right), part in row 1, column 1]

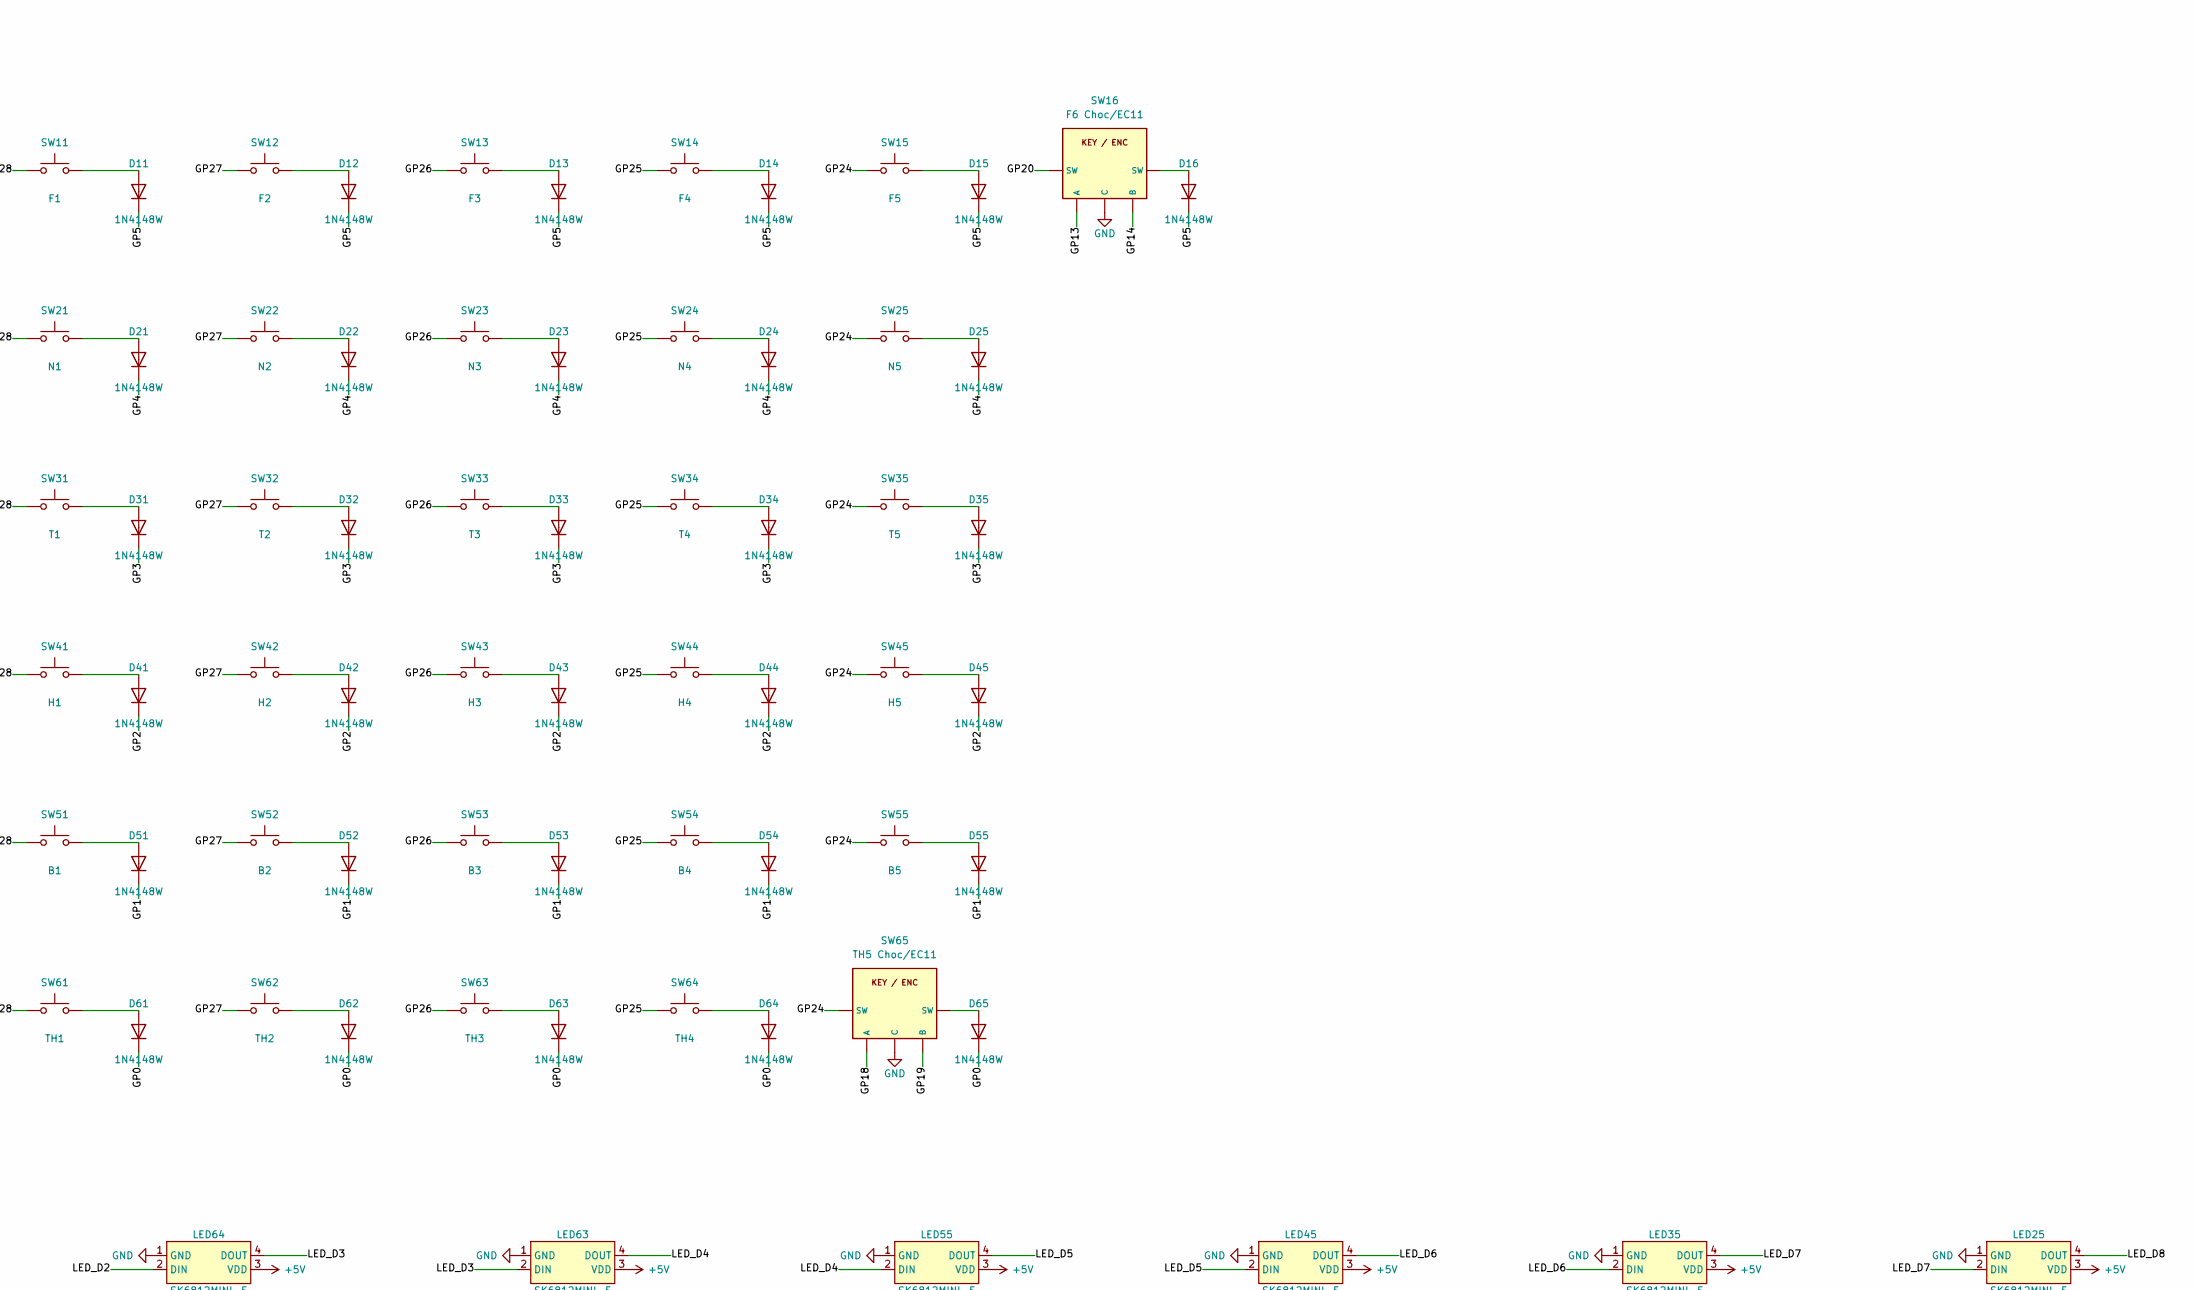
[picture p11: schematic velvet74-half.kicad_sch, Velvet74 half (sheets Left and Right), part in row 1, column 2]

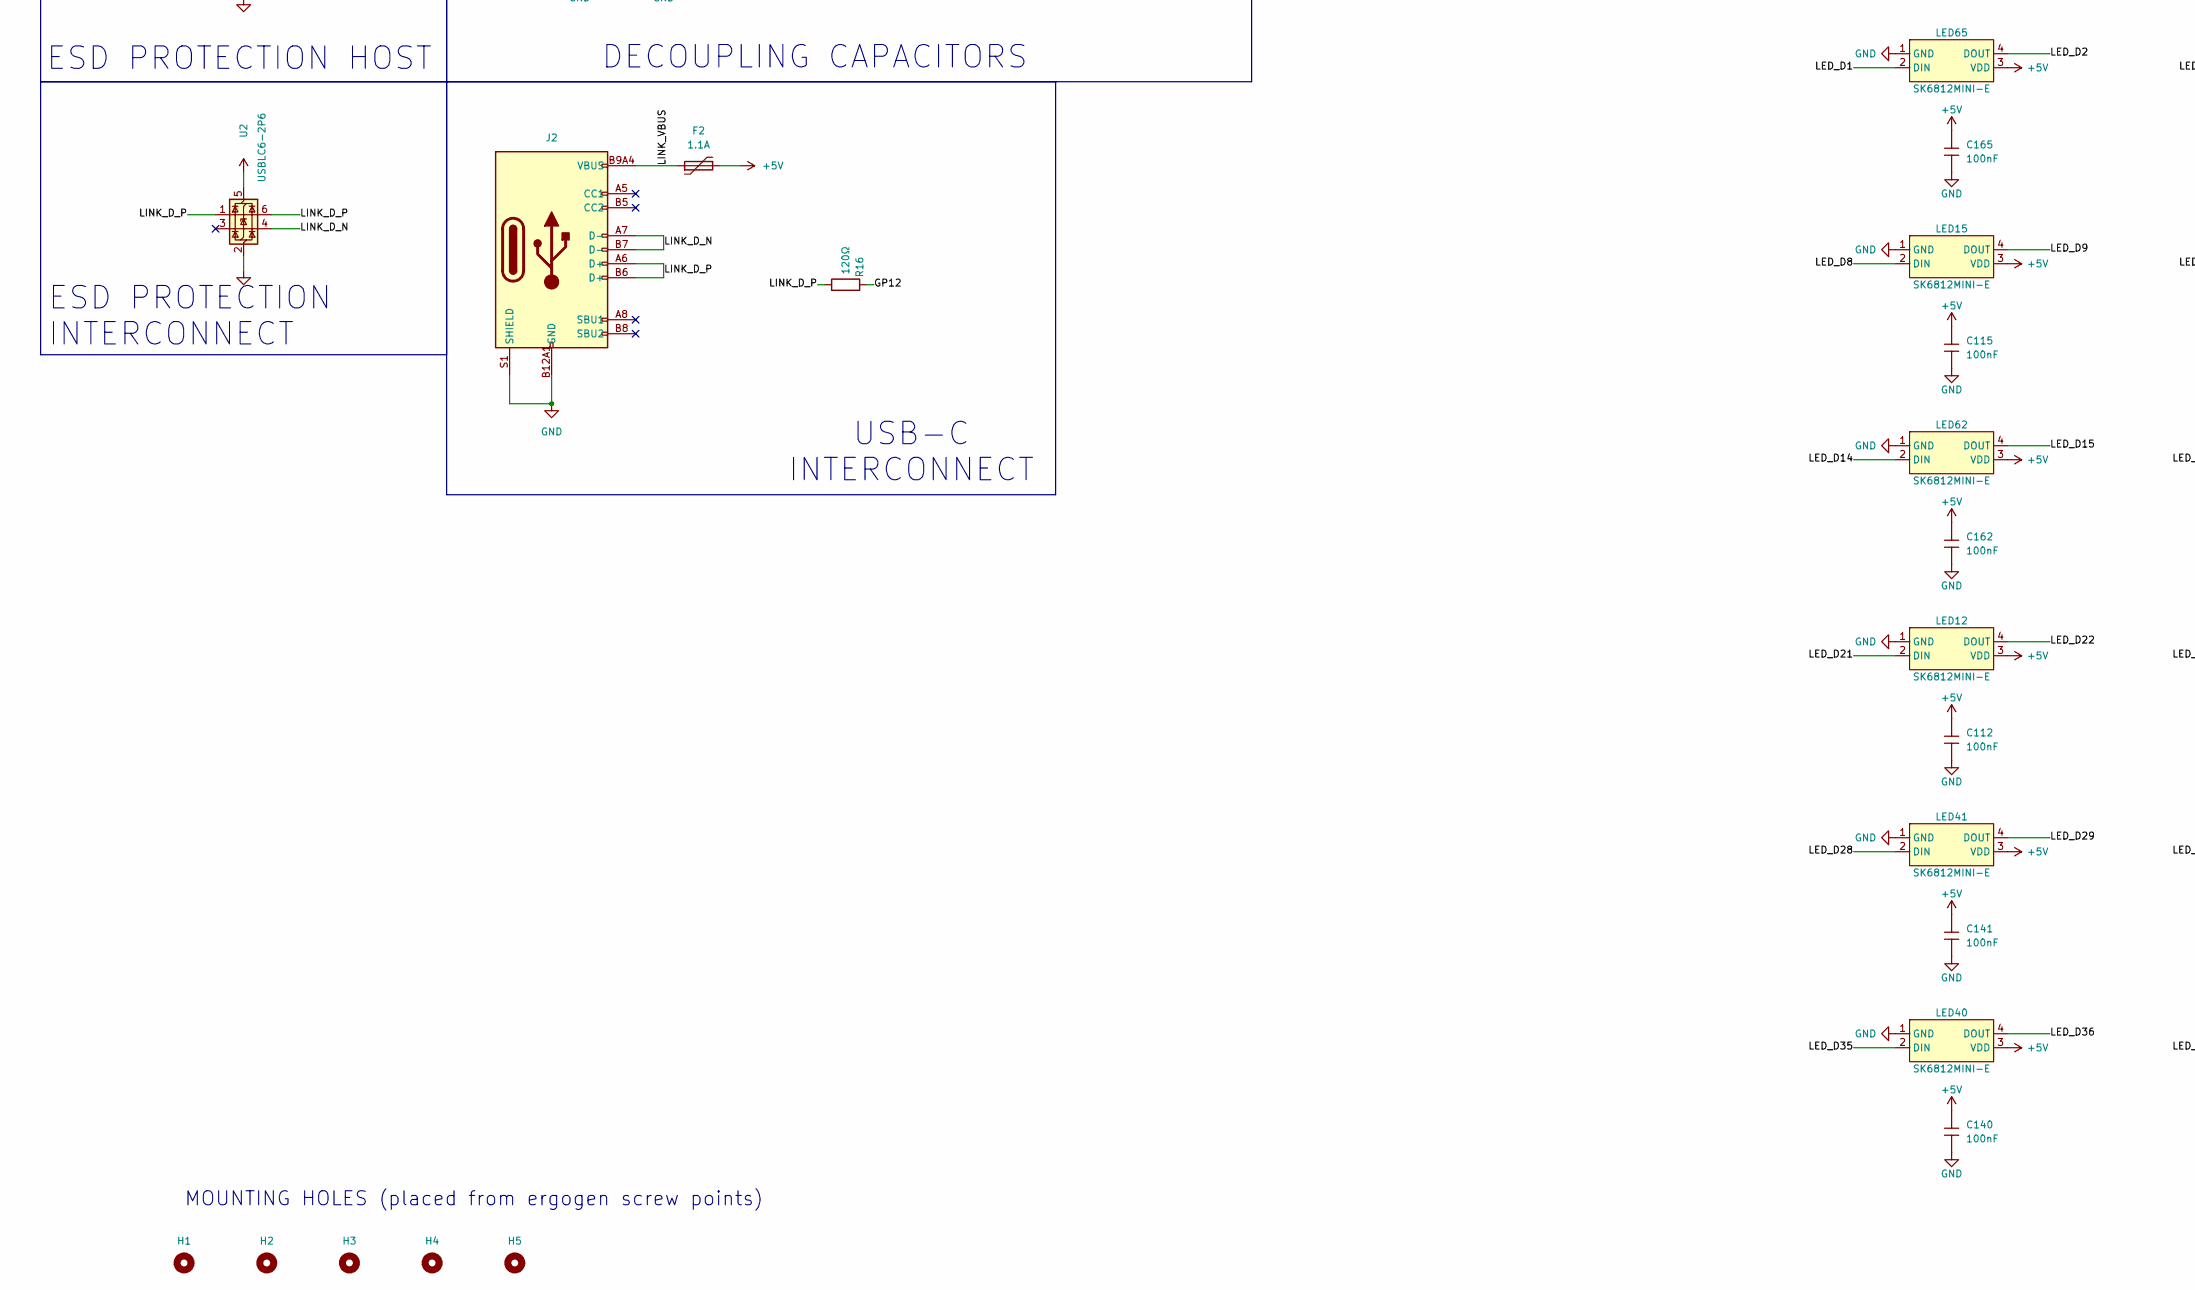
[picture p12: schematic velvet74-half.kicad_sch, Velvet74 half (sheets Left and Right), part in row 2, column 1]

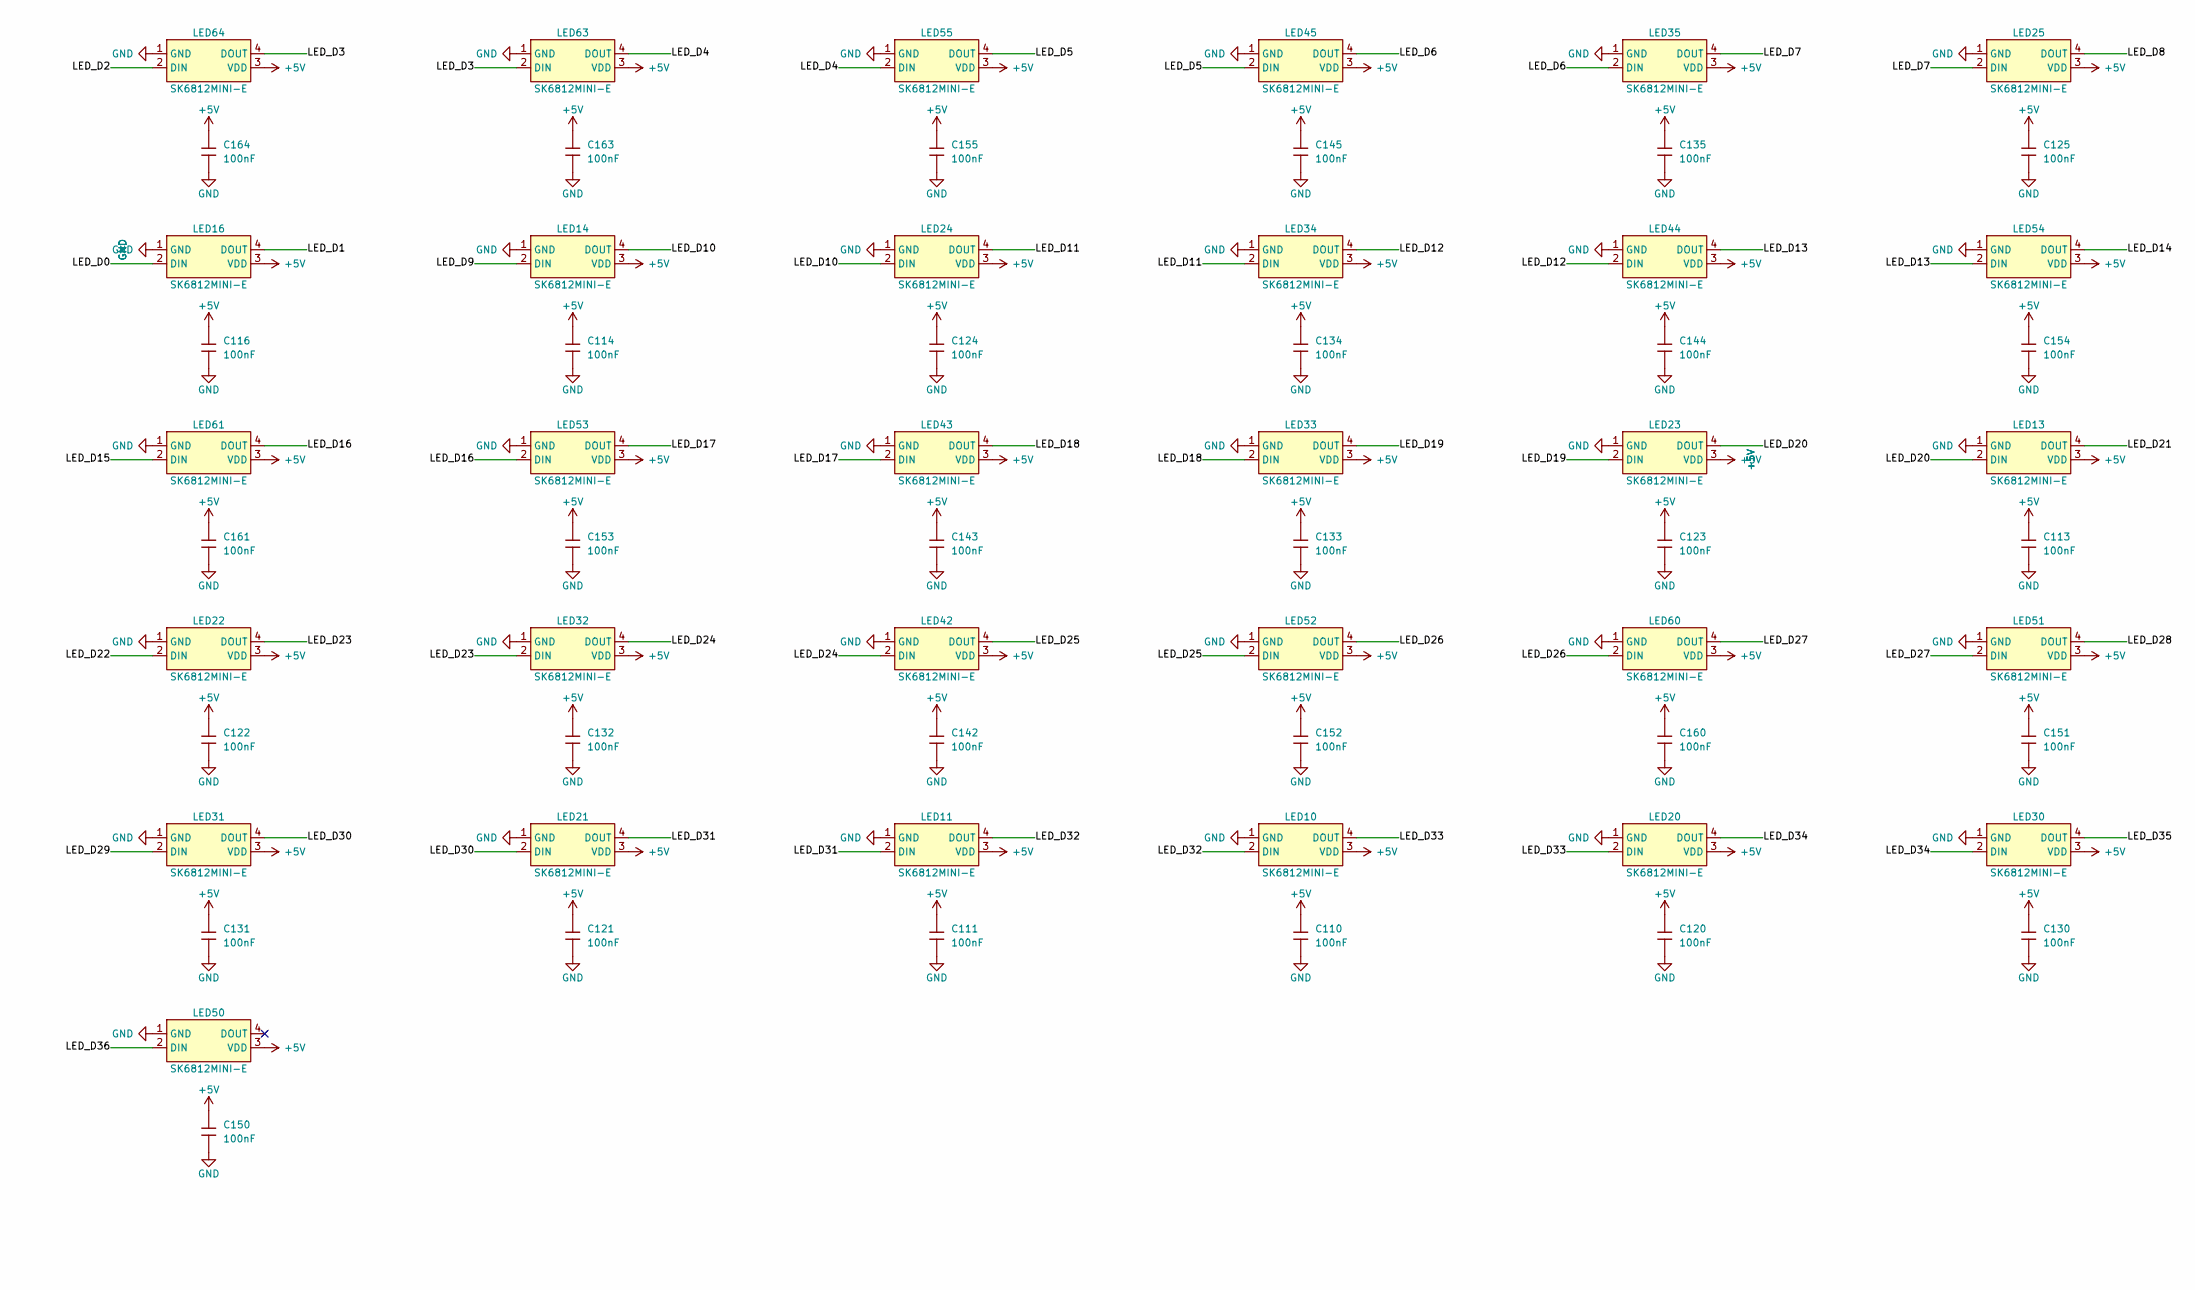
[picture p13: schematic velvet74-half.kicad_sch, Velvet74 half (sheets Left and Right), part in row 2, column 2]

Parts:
C1, C4: 15pF; C_0402; Voltage Rated 50V; Tolerance ±5%; Part 0402CG150J500NT; LCSC C1548
C3, C5, C6, C10, C11, C12, C13, C14, C15, C16, C17, C30, C110, C111, C112, C113, C114, C115, C116, C120, C121, C122, C123, C124, C125, C130, C131, C132, C133, C134, C135, C140, C141, C142, C143, C144, C145, C150, C151, C152, C153, C154, C155, C160, C161, C162, C163, C164, C165: 100nF; C_0402; Voltage Rated 16V; Tolerance ±10%; Part CL05B104KO5NNNC; LCSC C1525
C7, C8, C19, C20: 1uF; C_0402; Voltage Rated 25V; Tolerance ±10%; Part CL05A105KA5NQNC; LCSC C52923
C9: 10uF; C_0603; Voltage Rated 10V; Tolerance ±10%; Part CL10A106KP8NNNC; LCSC C19702
C18: 10uF; C_0603; Voltage Rated 10V; Part CL10A106KP8NNNC; LCSC C19702
D1: B5819W SL; D_SOD-123; Forward Voltage (Vf@If) 600mV@1A; Reverse Voltage (Vr) 40V; Part B5819W SL; LCSC C8598
D2: SMF5.0A; D_SOD-123FL; Part SMF5.0A; LCSC C19077497
D10, D11, D12, D13, D14, D15, D16, D20, D21, D22, D23, D24, D25, D30, D31, D32, D33, D34, D35, D40, D41, D42, D43, D44, D45, D50, D51, D52, D53, D54, D55, D60, D61, D62, D63, D64, D65: 1N4148W; D_SOD-123; Forward Voltage (Vf@If) 1V@50mA; Reverse Voltage (Vr) 75V; Part 1N4148W; LCSC C81598
F1, F2: 1.1A; Fuse_1206_3216Metric; Part 1206L110THYR; LCSC C126818
H1, H2, H3, H4, H5: MountingHole; MountingHole_2.2mm_M2
J1, J2: Connector, USB-TYPE-C-16P; USB_C_Receptacle_HongCheng_HC-TYPE-C-16P_MidMount; LCSC C19274022
J3: OLED 128x32; PinHeader_1x04_P2.54mm_Vertical
JP1: HAND L=1-2 R=2-3; SolderJumper-3_P1.3mm_Open_RoundedPad1.0x1.5mm_NumberLabels
LED10, LED11, LED12, LED13, LED14, LED15, LED16, LED20, LED21, LED22, LED23, LED24, LED25, LED30, LED31, LED32, LED33, LED34, LED35, LED40, LED41, LED42, LED43, LED44, LED45, LED50, LED51, LED52, LED53, LED54, LED55, LED60, LED61, LED62, LED63, LED64, LED65: SK6812MINI-E; LED-SMD_4P-L3.2-W2.8-LS5.9_SK6812MINI-E; MPN SK6812MINI-E; LCSC Part C5149201
R2, R4: 1kΩ; R_0402; Overload Voltage (Max) 50V; Tolerance ±1%; Part 0402WGF1001TCE; LCSC C11702
R5, R6: 5.1kΩ; R_0402; Part 0402WGF5101TCE; LCSC C25905
R7, R8: 27Ω; R_0402; Part 0402WGF270JTCE; LCSC C25100
R10, R11: 10kΩ; R_0402; Overload Voltage (Max) 50V; Tolerance ±1%; Part 0402WGF1002TCE; LCSC C25744
R15: 470Ω; R_0402; Overload Voltage (Max) 50V; Tolerance ±1%; Part 0402WGF4700TCE; LCSC C25117
R16: 120Ω; R_0402; Overload Voltage (Max) 50V; Tolerance ±1%; Part 0402WGF1200TCE; LCSC C25079
SW1: BOOT; SW_Push_1P1T_XUNPU_TS-1088-AR02016; Part TS-1088-AR02016; LCSC C720477
SW2: RESET; SW_Push_1P1T_XUNPU_TS-1088-AR02016; Part TS-1088-AR02016; LCSC C720477
SW10: F0; SW_Choc_V1V2_Hotswap_1.00u
SW11: F1; SW_Choc_V1V2_Hotswap_1.00u
SW12: F2; SW_Choc_V1V2_Hotswap_1.00u
SW13: F3; SW_Choc_V1V2_Hotswap_1.00u
SW14: F4; SW_Choc_V1V2_Hotswap_1.00u
SW15: F5; SW_Choc_V1V2_Hotswap_1.00u
SW16: F6 Choc/EC11; SW_Choc_V1V2_Hotswap_EC11_Combo
SW20: N0; SW_Choc_V1V2_Hotswap_1.00u
SW21: N1; SW_Choc_V1V2_Hotswap_1.00u
SW22: N2; SW_Choc_V1V2_Hotswap_1.00u
SW23: N3; SW_Choc_V1V2_Hotswap_1.00u
SW24: N4; SW_Choc_V1V2_Hotswap_1.00u
SW25: N5; SW_Choc_V1V2_Hotswap_1.00u
SW30: T0; SW_Choc_V1V2_Hotswap_1.00u
SW31: T1; SW_Choc_V1V2_Hotswap_1.00u
SW32: T2; SW_Choc_V1V2_Hotswap_1.00u
SW33: T3; SW_Choc_V1V2_Hotswap_1.00u
SW34: T4; SW_Choc_V1V2_Hotswap_1.00u
SW35: T5; SW_Choc_V1V2_Hotswap_1.00u
SW40: H0; SW_Choc_V1V2_Hotswap_1.00u
SW41: H1; SW_Choc_V1V2_Hotswap_1.00u
SW42: H2; SW_Choc_V1V2_Hotswap_1.00u
SW43: H3; SW_Choc_V1V2_Hotswap_1.00u
SW44: H4; SW_Choc_V1V2_Hotswap_1.00u
SW45: H5; SW_Choc_V1V2_Hotswap_1.00u
SW50: B0; SW_Choc_V1V2_Hotswap_1.00u
SW51: B1; SW_Choc_V1V2_Hotswap_1.00u
SW52: B2; SW_Choc_V1V2_Hotswap_1.00u
SW53: B3; SW_Choc_V1V2_Hotswap_1.00u
SW54: B4; SW_Choc_V1V2_Hotswap_1.00u
SW55: B5; SW_Choc_V1V2_Hotswap_1.00u
SW60: TH0; SW_Choc_V1V2_Hotswap_1.00u
SW61: TH1; SW_Choc_V1V2_Hotswap_1.00u
SW62: TH2; SW_Choc_V1V2_Hotswap_1.00u
SW63: TH3; SW_Choc_V1V2_Hotswap_1.00u
SW64: TH4; SW_Choc_V1V2_Hotswap_1.50u
SW65: TH5 Choc/EC11; SW_Choc_V1V2_Hotswap_EC11_Combo
U1: RP2040; QFN-56-1EP_7x7mm_P0.4mm_EP3.2x3.2mm_ThermalVias; LCSC C2040
U2, U4: USBLC6-2P6; SOT-563_USBLC6-2P6; Part USBLC6-2P6; LCSC C49451919
U3: ZD25Q128CWIGR; WSON-8-1EP_6x5mm_P1.27mm_EP3.4x4mm; Part ZD25Q128CWIGR; LCSC C53959302
U5: AP2112K-3.3; SOT-23-5_L3.0-W1.7-P0.95-LS2.8-BL; Part AP2112K-3.3TRG1; LCSC C51118
U6: SN74LV1T34DBVR; SOT-23-5; LCSC C100024
X1: ABM8-272-T3; CRYSTAL-SMD_4P-L3.2-W2.5-BL; Frequency Tolerance ±30ppm; Part ABM8-272-T3; LCSC C20625731

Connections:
/Left/+1V1: C5.1, C6.1, C8.1, U1.23 (DVDD), U1.45 (VREG_VOUT), U1.50 (DVDD)
/Left/+3.3V: C3.1, C7.1, C9.1, C10.1, C11.1, C12.1, C13.1, C14.1, C15.1, C16.1, C17.1, C19.1, J3.2, JP1.1 (A), U1.1 (IOVDD), U1.10 (IOVDD), U1.22 (IOVDD), U1.33 (IOVDD), U1.42 (IOVDD), U1.43 (ADC_AVDD), U1.44 (VREG_IN), U1.48 (USB_VDD), U1.49 (IOVDD), U3.8 (VCC), U5.5 (VOUT)
/Left/+5V: C18.1, C20.1, C30.1, C110.1, C111.1, C112.1, C113.1, C114.1, C115.1, C116.1, C120.1, C121.1, C122.1, C123.1, C124.1, C125.1, C130.1, C131.1, C132.1, C133.1, C134.1, C135.1, C140.1, C141.1, C142.1, C143.1, C144.1, C145.1, C150.1, C151.1, C152.1, C153.1, C154.1, C155.1, C160.1, C161.1, C162.1, C163.1, C164.1, C165.1, D1.1, F2.2, LED10.3 (VDD), LED11.3 (VDD), LED12.3 (VDD), LED13.3 (VDD), LED14.3 (VDD), LED15.3 (VDD), LED16.3 (VDD), LED20.3 (VDD), LED21.3 (VDD), LED22.3 (VDD), LED23.3 (VDD), LED24.3 (VDD), LED25.3 (VDD), LED30.3 (VDD), LED31.3 (VDD), LED32.3 (VDD), LED33.3 (VDD), LED34.3 (VDD), LED35.3 (VDD), LED40.3 (VDD), LED41.3 (VDD), LED42.3 (VDD), LED43.3 (VDD), LED44.3 (VDD), LED45.3 (VDD), LED50.3 (VDD), LED51.3 (VDD), LED52.3 (VDD), LED53.3 (VDD), LED54.3 (VDD), LED55.3 (VDD), LED60.3 (VDD), LED61.3 (VDD), LED62.3 (VDD), LED63.3 (VDD), LED64.3 (VDD), LED65.3 (VDD), U2.5 (VBUS), U4.5 (VBUS), U5.1 (VIN), U5.3 (EN), U6.5 (VCC)
/Left/CLK: U1.52 (QSPI_SCLK), U3.6 (CLK)
/Left/D+: J1.A6 (D+), J1.B6 (D+), R7.1, U4.1 (I/O1), U4.6 (I/O1)
/Left/D-: J1.A7 (D-), J1.B7 (D-), R8.1, U4.3 (I/O2), U4.4 (I/O2)
/Left/GND: C1.1, C3.2, C4.1, C5.2, C6.2, C7.2, C8.2, C9.2, C10.2, C11.2, C12.2, C13.2, C14.2, C15.2, C16.2, C17.2, C18.2, C19.2, C20.2, C30.2, C110.2, C111.2, C112.2, C113.2, C114.2, C115.2, C116.2, C120.2, C121.2, C122.2, C123.2, C124.2, C125.2, C130.2, C131.2, C132.2, C133.2, C134.2, C135.2, C140.2, C141.2, C142.2, C143.2, C144.2, C145.2, C150.2, C151.2, C152.2, C153.2, C154.2, C155.2, C160.2, C161.2, C162.2, C163.2, C164.2, C165.2, D2.2, J1.A12B1 (GND), J1.B12A1 (GND), J1.S1 (SHIELD), J2.A12B1 (GND), J2.B12A1 (GND), J2.S1 (SHIELD), J3.1, JP1.3 (B), LED10.1 (GND), LED11.1 (GND), LED12.1 (GND), LED13.1 (GND), LED14.1 (GND), LED15.1 (GND), LED16.1 (GND), LED20.1 (GND), LED21.1 (GND), LED22.1 (GND), LED23.1 (GND), LED24.1 (GND), LED25.1 (GND), LED30.1 (GND), LED31.1 (GND), LED32.1 (GND), LED33.1 (GND), LED34.1 (GND), LED35.1 (GND), LED40.1 (GND), LED41.1 (GND), LED42.1 (GND), LED43.1 (GND), LED44.1 (GND), LED45.1 (GND), LED50.1 (GND), LED51.1 (GND), LED52.1 (GND), LED53.1 (GND), LED54.1 (GND), LED55.1 (GND), LED60.1 (GND), LED61.1 (GND), LED62.1 (GND), LED63.1 (GND), LED64.1 (GND), LED65.1 (GND), R5.2, R6.2, R11.2, SW1.1, SW2.1, SW16.C, SW65.C, U1.19 (TESTEN), U1.57 (GND)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
/Left/GP0: D60.1, D61.1, D62.1, D63.1, D64.1, D65.1, U1.2 (GPIO0)
/Left/GP1: D50.1, D51.1, D52.1, D53.1, D54.1, D55.1, U1.3 (GPIO1)
/Left/GP2: D40.1, D41.1, D42.1, D43.1, D44.1, D45.1, U1.4 (GPIO2)
/Left/GP3: D30.1, D31.1, D32.1, D33.1, D34.1, D35.1, U1.5 (GPIO3)
/Left/GP4: D20.1, D21.1, D22.1, D23.1, D24.1, D25.1, U1.6 (GPIO4)
/Left/GP5: D10.1, D11.1, D12.1, D13.1, D14.1, D15.1, D16.1, U1.7 (GPIO5)
/Left/GP6: J3.4, U1.8 (GPIO6)
/Left/GP7: J3.3, U1.9 (GPIO7)
/Left/GP8: JP1.2 (C), U1.11 (GPIO8)
/Left/GP9: R10.2, R11.1, U1.12 (GPIO9)
/Left/GP10: U1.13 (GPIO10), U6.2
/Left/GP12: R16.2, U1.15 (GPIO12)
/Left/GP13: SW16.A, U1.16 (GPIO13)
/Left/GP14: SW16.B, U1.17 (GPIO14)
/Left/GP18: SW65.A, U1.29 (GPIO18)
/Left/GP19: SW65.B, U1.30 (GPIO19)
/Left/GP20: SW16.1 (SW), U1.31 (GPIO20)
/Left/GP24: SW15.1, SW25.1, SW35.1, SW45.1, SW55.1, SW65.1 (SW), U1.36 (GPIO24)
/Left/GP25: SW14.1, SW24.1, SW34.1, SW44.1, SW54.1, SW64.1, U1.37 (GPIO25)
/Left/GP26: SW13.1, SW23.1, SW33.1, SW43.1, SW53.1, SW63.1, U1.38 (GPIO26_ADC0)
/Left/GP27: SW12.1, SW22.1, SW32.1, SW42.1, SW52.1, SW62.1, U1.39 (GPIO27_ADC1)
/Left/GP28: SW11.1, SW21.1, SW31.1, SW41.1, SW51.1, SW61.1, U1.40 (GPIO28_ADC2)
/Left/GP29: SW10.1, SW20.1, SW30.1, SW40.1, SW50.1, SW60.1, U1.41 (GPIO29_ADC3)
/Left/LED_BUF: R15.1, U6.4
/Left/LED_D0: LED16.2 (DIN), R15.2
/Left/LED_D1: LED16.4 (DOUT), LED65.2 (DIN)
/Left/LED_D2: LED64.2 (DIN), LED65.4 (DOUT)
/Left/LED_D3: LED63.2 (DIN), LED64.4 (DOUT)
/Left/LED_D4: LED55.2 (DIN), LED63.4 (DOUT)
/Left/LED_D5: LED45.2 (DIN), LED55.4 (DOUT)
/Left/LED_D6: LED35.2 (DIN), LED45.4 (DOUT)
/Left/LED_D7: LED25.2 (DIN), LED35.4 (DOUT)
/Left/LED_D8: LED15.2 (DIN), LED25.4 (DOUT)
/Left/LED_D9: LED14.2 (DIN), LED15.4 (DOUT)
/Left/LED_D10: LED14.4 (DOUT), LED24.2 (DIN)
/Left/LED_D11: LED24.4 (DOUT), LED34.2 (DIN)
/Left/LED_D12: LED34.4 (DOUT), LED44.2 (DIN)
/Left/LED_D13: LED44.4 (DOUT), LED54.2 (DIN)
/Left/LED_D14: LED54.4 (DOUT), LED62.2 (DIN)
/Left/LED_D15: LED61.2 (DIN), LED62.4 (DOUT)
/Left/LED_D16: LED53.2 (DIN), LED61.4 (DOUT)
/Left/LED_D17: LED43.2 (DIN), LED53.4 (DOUT)
/Left/LED_D18: LED33.2 (DIN), LED43.4 (DOUT)
/Left/LED_D19: LED23.2 (DIN), LED33.4 (DOUT)
/Left/LED_D20: LED13.2 (DIN), LED23.4 (DOUT)
/Left/LED_D21: LED12.2 (DIN), LED13.4 (DOUT)
/Left/LED_D22: LED12.4 (DOUT), LED22.2 (DIN)
/Left/LED_D23: LED22.4 (DOUT), LED32.2 (DIN)
/Left/LED_D24: LED32.4 (DOUT), LED42.2 (DIN)
/Left/LED_D25: LED42.4 (DOUT), LED52.2 (DIN)
/Left/LED_D26: LED52.4 (DOUT), LED60.2 (DIN)
/Left/LED_D27: LED51.2 (DIN), LED60.4 (DOUT)
/Left/LED_D28: LED41.2 (DIN), LED51.4 (DOUT)
/Left/LED_D29: LED31.2 (DIN), LED41.4 (DOUT)
/Left/LED_D30: LED21.2 (DIN), LED31.4 (DOUT)
/Left/LED_D31: LED11.2 (DIN), LED21.4 (DOUT)
/Left/LED_D32: LED10.2 (DIN), LED11.4 (DOUT)
/Left/LED_D33: LED10.4 (DOUT), LED20.2 (DIN)
/Left/LED_D34: LED20.4 (DOUT), LED30.2 (DIN)
/Left/LED_D35: LED30.4 (DOUT), LED40.2 (DIN)
/Left/LED_D36: LED40.4 (DOUT), LED50.2 (DIN)
/Left/LINK_D_N: J2.A7 (D-), J2.B7 (D-), U2.4 (I/O2)
/Left/LINK_D_P: J2.A6 (D+), J2.B6 (D+), R16.1, U2.1 (I/O1), U2.6 (I/O1)
/Left/LINK_VBUS: F2.1, J2.A9B4 (VBUS), J2.B9A4 (VBUS)
/Left/RUN: SW2.2, U1.26 (RUN)
/Left/SD0: U1.53 (QSPI_SD0), U3.5 (DI)
/Left/SD1: U1.55 (QSPI_SD1), U3.2 (DO)
/Left/SD2: U1.54 (QSPI_SD2), U3.3 (IO2)
/Left/SD3: U1.51 (QSPI_SD3), U3.7 (IO3)
/Left/SS: R4.2, U1.56 (QSPI_SS), U3.1 (CS#)
/Left/USB_N: R8.2, U1.46 (USB_DM)
/Left/USB_P: R7.2, U1.47 (USB_DP)
/Left/VBUS: D2.1, F1.1, J1.A9B4 (VBUS), J1.B9A4 (VBUS), R10.1
/Left/VBUS_FUSED: D1.2, F1.2
/Left/XTAL_IN: C1.2, U1.20 (XIN), X1.3 (OSC)
/Left/XTAL_OUT: R2.2, U1.21 (XOUT)
unnamed: C4.2, R2.1, X1.1 (OSC)
unnamed: D10.2, SW10.2
unnamed: D11.2, SW11.2
unnamed: D12.2, SW12.2
unnamed: D13.2, SW13.2
unnamed: D14.2, SW14.2
unnamed: D15.2, SW15.2
unnamed: D16.2, SW16.2 (SW)
unnamed: D20.2, SW20.2
unnamed: D21.2, SW21.2
unnamed: D22.2, SW22.2
unnamed: D23.2, SW23.2
unnamed: D24.2, SW24.2
unnamed: D25.2, SW25.2
unnamed: D30.2, SW30.2
unnamed: D31.2, SW31.2
unnamed: D32.2, SW32.2
unnamed: D33.2, SW33.2
unnamed: D34.2, SW34.2
unnamed: D35.2, SW35.2
unnamed: D40.2, SW40.2
unnamed: D41.2, SW41.2
unnamed: D42.2, SW42.2
unnamed: D43.2, SW43.2
unnamed: D44.2, SW44.2
unnamed: D45.2, SW45.2
unnamed: D50.2, SW50.2
unnamed: D51.2, SW51.2
unnamed: D52.2, SW52.2
unnamed: D53.2, SW53.2
unnamed: D54.2, SW54.2
unnamed: D55.2, SW55.2
unnamed: D60.2, SW60.2
unnamed: D61.2, SW61.2
unnamed: D62.2, SW62.2
unnamed: D63.2, SW63.2
unnamed: D64.2, SW64.2
unnamed: D65.2, SW65.2 (SW)
unnamed: J1.A5 (CC1), R5.1
unnamed: J1.B5 (CC2), R6.1
unnamed: R4.1, SW1.2

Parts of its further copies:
C201, C204: 15pF; C_0402; Voltage Rated 50V; Tolerance ±5%; Part 0402CG150J500NT; LCSC C1548
C203, C205, C206, C210, C211, C212, C213, C214, C215, C216, C217, C230, C310, C311, C312, C313, C314, C315, C316, C320, C321, C322, C323, C324, C325, C330, C331, C332, C333, C334, C335, C340, C341, C342, C343, C344, C345, C350, C351, C352, C353, C354, C355, C360, C361, C362, C363, C364, C365: 100nF; C_0402; Voltage Rated 16V; Tolerance ±10%; Part CL05B104KO5NNNC; LCSC C1525
C207, C208, C219, C220: 1uF; C_0402; Voltage Rated 25V; Tolerance ±10%; Part CL05A105KA5NQNC; LCSC C52923
C209: 10uF; C_0603; Voltage Rated 10V; Tolerance ±10%; Part CL10A106KP8NNNC; LCSC C19702
C218: 10uF; C_0603; Voltage Rated 10V; Part CL10A106KP8NNNC; LCSC C19702
D201: B5819W SL; D_SOD-123; Forward Voltage (Vf@If) 600mV@1A; Reverse Voltage (Vr) 40V; Part B5819W SL; LCSC C8598
D202: SMF5.0A; D_SOD-123FL; Part SMF5.0A; LCSC C19077497
D210, D211, D212, D213, D214, D215, D216, D220, D221, D222, D223, D224, D225, D230, D231, D232, D233, D234, D235, D240, D241, D242, D243, D244, D245, D250, D251, D252, D253, D254, D255, D260, D261, D262, D263, D264, D265: 1N4148W; D_SOD-123; Forward Voltage (Vf@If) 1V@50mA; Reverse Voltage (Vr) 75V; Part 1N4148W; LCSC C81598
F201, F202: 1.1A; Fuse_1206_3216Metric; Part 1206L110THYR; LCSC C126818
H201, H202, H203, H204, H205: MountingHole; MountingHole_2.2mm_M2
J201, J202: Connector, USB-TYPE-C-16P; USB_C_Receptacle_HongCheng_HC-TYPE-C-16P_MidMount; LCSC C19274022
J203: OLED 128x32; PinHeader_1x04_P2.54mm_Vertical
JP201: HAND L=1-2 R=2-3; SolderJumper-3_P1.3mm_Open_RoundedPad1.0x1.5mm_NumberLabels
LED210, LED211, LED212, LED213, LED214, LED215, LED216, LED220, LED221, LED222, LED223, LED224, LED225, LED230, LED231, LED232, LED233, LED234, LED235, LED240, LED241, LED242, LED243, LED244, LED245, LED250, LED251, LED252, LED253, LED254, LED255, LED260, LED261, LED262, LED263, LED264, LED265: SK6812MINI-E; LED-SMD_4P-L3.2-W2.8-LS5.9_SK6812MINI-E; MPN SK6812MINI-E; LCSC Part C5149201
R202, R204: 1kΩ; R_0402; Overload Voltage (Max) 50V; Tolerance ±1%; Part 0402WGF1001TCE; LCSC C11702
R205, R206: 5.1kΩ; R_0402; Part 0402WGF5101TCE; LCSC C25905
R207, R208: 27Ω; R_0402; Part 0402WGF270JTCE; LCSC C25100
R210, R211: 10kΩ; R_0402; Overload Voltage (Max) 50V; Tolerance ±1%; Part 0402WGF1002TCE; LCSC C25744
R215: 470Ω; R_0402; Overload Voltage (Max) 50V; Tolerance ±1%; Part 0402WGF4700TCE; LCSC C25117
R216: 120Ω; R_0402; Overload Voltage (Max) 50V; Tolerance ±1%; Part 0402WGF1200TCE; LCSC C25079
SW201: BOOT; SW_Push_1P1T_XUNPU_TS-1088-AR02016; Part TS-1088-AR02016; LCSC C720477
SW202: RESET; SW_Push_1P1T_XUNPU_TS-1088-AR02016; Part TS-1088-AR02016; LCSC C720477
SW210: F0; SW_Choc_V1V2_Hotswap_1.00u
SW211: F1; SW_Choc_V1V2_Hotswap_1.00u
SW212: F2; SW_Choc_V1V2_Hotswap_1.00u
SW213: F3; SW_Choc_V1V2_Hotswap_1.00u
SW214: F4; SW_Choc_V1V2_Hotswap_1.00u
SW215: F5; SW_Choc_V1V2_Hotswap_1.00u
SW216: F6 Choc/EC11; SW_Choc_V1V2_Hotswap_EC11_Combo
SW220: N0; SW_Choc_V1V2_Hotswap_1.00u
SW221: N1; SW_Choc_V1V2_Hotswap_1.00u
SW222: N2; SW_Choc_V1V2_Hotswap_1.00u
SW223: N3; SW_Choc_V1V2_Hotswap_1.00u
SW224: N4; SW_Choc_V1V2_Hotswap_1.00u
SW225: N5; SW_Choc_V1V2_Hotswap_1.00u
SW230: T0; SW_Choc_V1V2_Hotswap_1.00u
SW231: T1; SW_Choc_V1V2_Hotswap_1.00u
SW232: T2; SW_Choc_V1V2_Hotswap_1.00u
SW233: T3; SW_Choc_V1V2_Hotswap_1.00u
SW234: T4; SW_Choc_V1V2_Hotswap_1.00u
SW235: T5; SW_Choc_V1V2_Hotswap_1.00u
SW240: H0; SW_Choc_V1V2_Hotswap_1.00u
SW241: H1; SW_Choc_V1V2_Hotswap_1.00u
SW242: H2; SW_Choc_V1V2_Hotswap_1.00u
SW243: H3; SW_Choc_V1V2_Hotswap_1.00u
SW244: H4; SW_Choc_V1V2_Hotswap_1.00u
SW245: H5; SW_Choc_V1V2_Hotswap_1.00u
SW250: B0; SW_Choc_V1V2_Hotswap_1.00u
SW251: B1; SW_Choc_V1V2_Hotswap_1.00u
SW252: B2; SW_Choc_V1V2_Hotswap_1.00u
SW253: B3; SW_Choc_V1V2_Hotswap_1.00u
SW254: B4; SW_Choc_V1V2_Hotswap_1.00u
SW255: B5; SW_Choc_V1V2_Hotswap_1.00u
SW260: TH0; SW_Choc_V1V2_Hotswap_1.00u
SW261: TH1; SW_Choc_V1V2_Hotswap_1.00u
SW262: TH2; SW_Choc_V1V2_Hotswap_1.00u
SW263: TH3; SW_Choc_V1V2_Hotswap_1.00u
SW264: TH4; SW_Choc_V1V2_Hotswap_1.50u
SW265: TH5 Choc/EC11; SW_Choc_V1V2_Hotswap_EC11_Combo
U201: RP2040; QFN-56-1EP_7x7mm_P0.4mm_EP3.2x3.2mm_ThermalVias; LCSC C2040
U202, U204: USBLC6-2P6; SOT-563_USBLC6-2P6; Part USBLC6-2P6; LCSC C49451919
U203: ZD25Q128CWIGR; WSON-8-1EP_6x5mm_P1.27mm_EP3.4x4mm; Part ZD25Q128CWIGR; LCSC C53959302
U205: AP2112K-3.3; SOT-23-5_L3.0-W1.7-P0.95-LS2.8-BL; Part AP2112K-3.3TRG1; LCSC C51118
U206: SN74LV1T34DBVR; SOT-23-5; LCSC C100024
X201: ABM8-272-T3; CRYSTAL-SMD_4P-L3.2-W2.5-BL; Frequency Tolerance ±30ppm; Part ABM8-272-T3; LCSC C20625731

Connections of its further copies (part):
/Right/+1V1: C205.1, C206.1, C208.1, U201.23 (DVDD), U201.45 (VREG_VOUT), U201.50 (DVDD)
/Right/+3.3V: C203.1, C207.1, C209.1, C210.1, C211.1, C212.1, C213.1, C214.1, C215.1, C216.1, C217.1, C219.1, J203.2, JP201.1 (A), U201.1 (IOVDD), U201.10 (IOVDD), U201.22 (IOVDD), U201.33 (IOVDD), U201.42 (IOVDD), U201.43 (ADC_AVDD), U201.44 (VREG_IN), U201.48 (USB_VDD), U201.49 (IOVDD), U203.8 (VCC), U205.5 (VOUT)
/Right/+5V: C218.1, C220.1, C230.1, C310.1, C311.1, C312.1, C313.1, C314.1, C315.1, C316.1, C320.1, C321.1, C322.1, C323.1, C324.1, C325.1, C330.1, C331.1, C332.1, C333.1, C334.1, C335.1, C340.1, C341.1, C342.1, C343.1, C344.1, C345.1, C350.1, C351.1, C352.1, C353.1, C354.1, C355.1, C360.1, C361.1, C362.1, C363.1, C364.1, C365.1, D201.1, F202.2, LED210.3 (VDD), LED211.3 (VDD), LED212.3 (VDD), LED213.3 (VDD), LED214.3 (VDD), LED215.3 (VDD), LED216.3 (VDD), LED220.3 (VDD), LED221.3 (VDD), LED222.3 (VDD), LED223.3 (VDD), LED224.3 (VDD), LED225.3 (VDD), LED230.3 (VDD), LED231.3 (VDD), LED232.3 (VDD), LED233.3 (VDD), LED234.3 (VDD), LED235.3 (VDD), LED240.3 (VDD), LED241.3 (VDD), LED242.3 (VDD), LED243.3 (VDD), LED244.3 (VDD), LED245.3 (VDD), LED250.3 (VDD), LED251.3 (VDD), LED252.3 (VDD), LED253.3 (VDD), LED254.3 (VDD), LED255.3 (VDD), LED260.3 (VDD), LED261.3 (VDD), LED262.3 (VDD), LED263.3 (VDD), LED264.3 (VDD), LED265.3 (VDD), U202.5 (VBUS), U204.5 (VBUS), U205.1 (VIN), U205.3 (EN), U206.5 (VCC)
/Right/CLK: U201.52 (QSPI_SCLK), U203.6 (CLK)
/Right/D+: J201.A6 (D+), J201.B6 (D+), R207.1, U204.1 (I/O1), U204.6 (I/O1)
/Right/D-: J201.A7 (D-), J201.B7 (D-), R208.1, U204.3 (I/O2), U204.4 (I/O2)
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

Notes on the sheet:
USB-C-16P-2A + FUSE LDO-5V-->3V3
DECOUPLING CAPACITORS
ESD PROTECTION INTERCONNECT
16MB-FLASH
12MHZ-CRYSTAL
USB-C INTERCONNECT
ESD PROTECTION HOST
MOUNTING HOLES (placed from ergogen screw points)

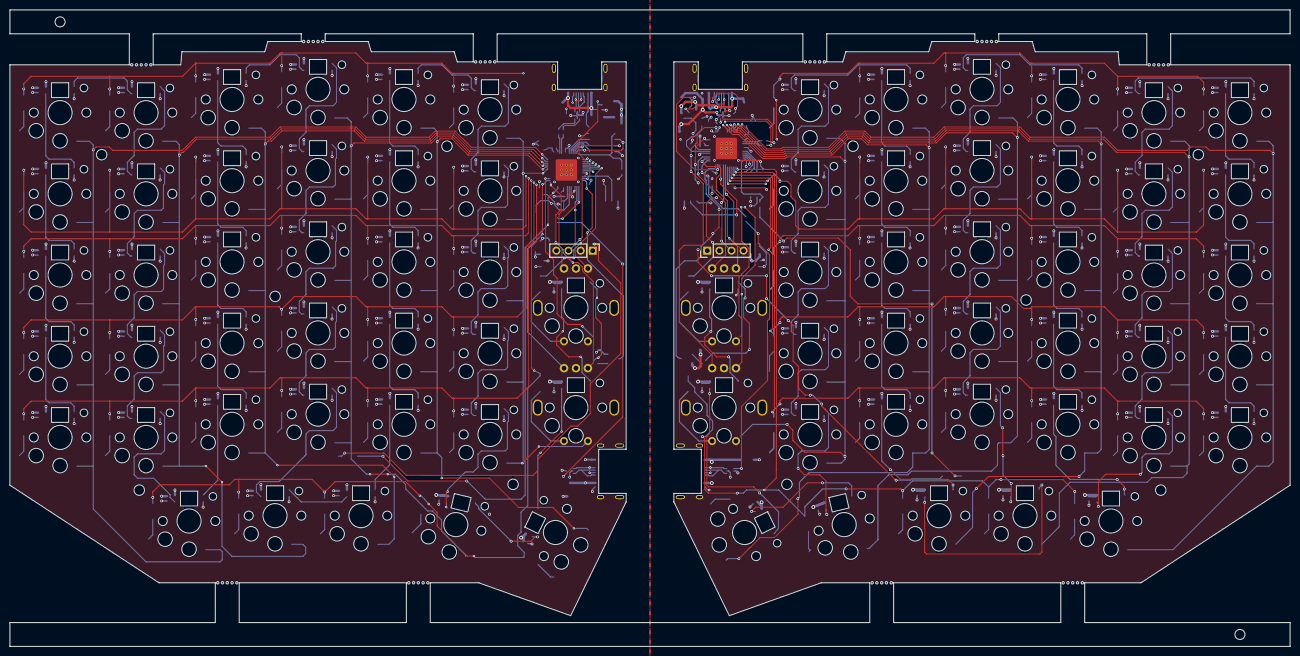
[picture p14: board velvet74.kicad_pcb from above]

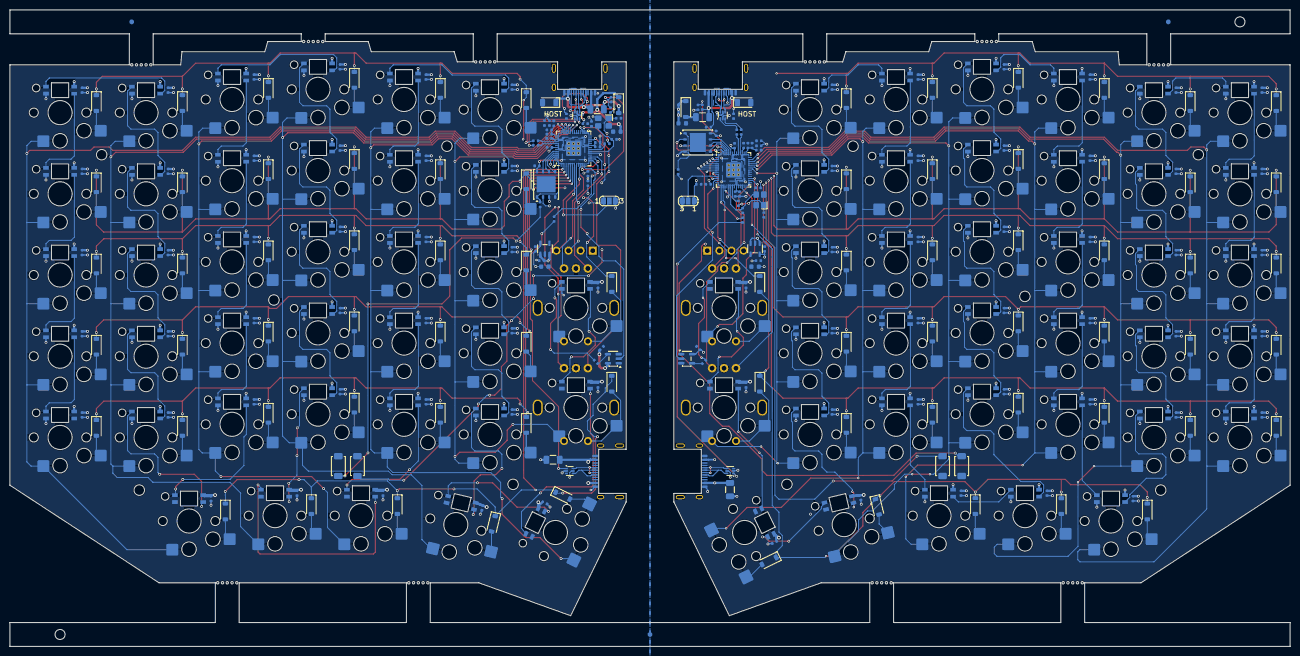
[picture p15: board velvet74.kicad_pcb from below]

Board: 4 copper layers, 268.0 x 133.2 mm, 415 parts (317 on the bottom side), 248 nets.

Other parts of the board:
FID1, FID2, FID3: Fiducial_1mm_Mask2mm
MB1, MB2, MB3, MB4, MB5, MB6, MB7, MB8, MB9, MB10: MouseBite_5x0.5mm_P1mm
TH1, TH2: MountingHole_2.1mm

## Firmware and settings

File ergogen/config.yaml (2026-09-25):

# my-soffle left half: key geometry, board outline and case.
# Ergogen owns geometry only. Parts, nets and JLC data live in the KiCad schematic;
# scripts/place_from_ergogen.py moves the schematic's footprints onto these points.
#
# Geometry source: Keebart Sofle Choc Pro firmware layout (keyboard.json) at Choc
# spacing, plus an F-row on top and a second encoder above Keebart's knob.
# Every key carries row_code/col_index so SW<row_code><col_index> is its schematic reference,
# and led: north|east|south|west for the side of the key its per-key LED sits on.

meta:
  engine: 4.2.1
  name: my-soffle

units:
  kx: cx # 18
  ky: cy # 17
  # Keebart column heights relative to pinky, from keyboard.json (0.125u steps)
  # pinky and pinky2 sit a little higher than Keebart's firmware layout on the real board
  pinky_lift: 1.5
  stagger_ring: 0.25 ky - pinky_lift
  stagger_middle: 0.125 ky
  stagger_index: -0.125 ky
  stagger_outer: -0.125 ky
  # tray case: the PCB drops in from the top, parts face the floor, the switch plate closes it
  wall: 2            # side wall thickness
  # 8.2 mm total. Thicknesses measured off a Keebart Sofle Choc Pro BT: FR4 plate 0.75, printed spacer 1.6,
  # PCB 1.6. The USB-C is mid-mount, so it no longer sets the standoff. floor is the balancing term.
  floor: 2.05        # floor thickness under the PCB
  fit: 0.2           # clearance between the PCB edge and the wall
  pcb_t: 1.6
  socket_h: 1.85     # Kailh Choc hotswap socket: the tallest thing under the board once the USB-C is sunk
  standoff: 2.2      # gap under the PCB, set by socket_h with 0.35 mm of slack
  # J3's OLED header and the two EC11 encoders (SW16, SW65) sit body-up on F and push their leads into this
  # gap. With only 2.2 mm there they must be cropped flush; untrimmed they reach about 3 mm and will foul.
  # The spacer's thickness is set by the OLED module: the plate rests on the module's glass, so module
  # PCB + glass must come to spacer_t. Confirm the module's total thickness before printing one.
  spacer_t: 1.6      # 3D printed spacer between PCB and plate; the OLED module lies in a pocket in it
  # FR4 top plate, 0.8 mm: JLC's nearest to the measured 0.75 (0.6 is not offered). Kailh's drawings put the
  # switch's rim 2.20 mm above its bottom (Choc v1 PG1350 and v2 PG1353 alike), so any plate top above
  # spacer_t + 0.6 lifts the switches off the PCB onto the rim: 0.2 mm here, 0.15 on the Keebart. Do not go
  # thicker. The clips grip plates up to 1.30 (v1) or 1.65 mm (v2), so they do not hold on 0.8 mm: the switch
  # is held by its hotswap socket and the plate is a cover rather than a structural switch plate.
  plate_t: 0.8
  # M2 countersunk screws down through the plate into a pillar or threaded insert in the case. Countersunk
  # because a proud head has nowhere to sit: keycaps cover 79% of the board, so only a flush head clears them.
  screw_d: 2.2       # M2 clearance hole
  screw_r: screw_d / 2
  # Boss under each screw: a plain pillar from the floor to the PCB underside, threading between the hotswap
  # sockets (only 0.35 mm of clear height below them, so no wide base). It holds a CNC Kitchen M2 x 3.0 heat-set
  # insert (3.6 mm knurl) in a blind 3.2 mm hole; the pillar is 4.25 mm tall against their 4 mm minimum. The
  # wall is 0.8 mm, under CNC Kitchen's 1.3 mm minimum, because H2 has only 2.61 mm to SW15's socket; every
  # screw point keeps boss_r + 0.2 mm to the nearest socket, pad, part and pin hole. An aluminium case would
  # need a 1.6 mm tap drill for M2 instead.
  insert_r: 1.6      # 3.2 mm hole
  insert_depth: 3.5  # 3.0 mm insert plus room for the displaced plastic; leaves 0.75 mm of floor under it
  boss_r: insert_r + 0.8
  case_h: floor + standoff + pcb_t + spacer_t + plate_t
  # Rounded top and bottom outer edges. Ergogen only extrudes flat outlines, so each fillet is four bands of
  # fil_r / 4, each pulled in by the arc's inset at its mid-height: fil_r - sqrt(fil_r^2 - t^2), t = 1/8, 3/8,
  # 5/8, 7/8 of fil_r (worked out for fil_r = 1; redo the insets if it changes). The rim keeps 0.8 mm flat.
  fil_r: 1
  fil_s: fil_r / 4
  fil_d1: 0.0078
  fil_d2: 0.0729
  fil_d3: 0.2194
  fil_d4: 0.5159
  # Mid-mount USB-C, Hong Cheng HC-TYPE-C-16P-C16B (LCSC C19274022), mounted on B.Cu. The body sinks
  # usbc_sink up into the board from its underside, so on a 1.6 mm PCB it is flush with the board top and
  # hangs usbc_below under the board, inside the standoff (2.2 mm, 0.54 mm to spare). The spacer and plate see
  # nothing of it. It needs the 9.24 x 5.75 mm edge cutout that board_pcb subtracts (_port_slots).
  # The sink is dimensioned on the manufacturer drawing; the overall height is not, and 3.26 is scaled off
  # it (the drawing's 2.56 is the mating cavity, not the body). C10B and C08B sink 1.0 and 0.8 instead.
  usbc_h: 3.26
  usbc_sink: 1.6
  usbc_below: usbc_h - usbc_sink  # 1.66 under the board underside; keep standoff above this
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

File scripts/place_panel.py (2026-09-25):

"""Place the panel hardware on the breakoff tabs and rails: mouse bites, tooling holes and fiducials.

From a shell (pcbnew closed):
    "%LOCALAPPDATA%/Programs/KiCad/10.0/bin/python.exe" scripts/place_panel.py velvet74.kicad_pcb

Re-running it fails rather than duplicating parts. It overwrites the board it is given and rewrites the
neighbouring .kicad_pro, so run it on a scratch copy and put the board back.

Every part is board-only (not in the schematic), so the schematic parity check ignores them. Positions follow the
outline that make_both.js adds: 5 mm rails above and below the halves, joined by ten 5 mm tabs. It also adds the
keepouts that hold the pours off the rails and tabs, and unfills every zone (refill with kicad-cli or KiCad).
"""
import os
import sys

import pcbnew

F = pcbnew.FromMM
STOCK = os.path.join(os.environ['LOCALAPPDATA'], 'Programs', 'KiCad', '10.0', 'share', 'kicad', 'footprints')
PROJ = os.path.join(os.path.dirname(os.path.dirname(os.path.abspath(__file__))), 'lib', 'my-soffle.pretty')
# (library, footprint, reference, x, y, flip to the bottom side, rotation)
PARTS = [
    # mouse bites where each tab meets the board, rotated to lie along the horizontal edge
    (PROJ, 'MouseBite_5x0.5mm_P1mm', 'MB1', 77.0, 62.0, False, 90),
    (PROJ, 'MouseBite_5x0.5mm_P1mm', 'MB2', 113.0, 57.12, False, 90),
    (PROJ, 'MouseBite_5x0.5mm_P1mm', 'MB3', 149.0, 61.38, False, 90),
    (PROJ, 'MouseBite_5x0.5mm_P1mm', 'MB4', 218.0, 61.38, False, 90),
    (PROJ, 'MouseBite_5x0.5mm_P1mm', 'MB5', 254.0, 57.12, False, 90),
    (PROJ, 'MouseBite_5x0.5mm_P1mm', 'MB6', 290.0, 62.0, False, 90),
    (PROJ, 'MouseBite_5x0.5mm_P1mm', 'MB7', 95.0, 170.425, False, 90),
    (PROJ, 'MouseBite_5x0.5mm_P1mm', 'MB8', 135.0, 170.425, False, 90),
    (PROJ, 'MouseBite_5x0.5mm_P1mm', 'MB9', 232.0, 170.425, False, 90),
    (PROJ, 'MouseBite_5x0.5mm_P1mm', 'MB10', 272.0, 170.425, False, 90),
    # tooling holes in the rails, diagonally opposite (JLCPCB asks for 2 mm, as far apart as practical)
    (os.path.join(STOCK, 'MountingHole.pretty'), 'MountingHole_2.1mm', 'TH1', 60.0, 53.0, False, 0),
    (os.path.join(STOCK, 'MountingHole.pretty'), 'MountingHole_2.1mm', 'TH2', 307.0, 181.25, False, 0),
    # fiducials on the rails, on the bottom where every assembled part sits
    (os.path.join(STOCK, 'Fiducial.pretty'), 'Fiducial_1mm_Mask2mm', 'FID1', 75.0, 53.0, True, 0),
    (os.path.join(STOCK, 'Fiducial.pretty'), 'Fiducial_1mm_Mask2mm', 'FID2', 292.0, 53.0, True, 0),
    (os.path.join(STOCK, 'Fiducial.pretty'), 'Fiducial_1mm_Mask2mm', 'FID3', 183.5, 181.25, True, 0),
]


def add_part(b, lib, name, ref, x, y, flip, rot):
    """Add one board-only panel footprint; scripts/export_plate.py uses it for the plate panel too."""
    assert b.FindFootprintByReference(ref) is None, ref + ' already placed'
    fp = pcbnew.FootprintLoad(lib, name)
    assert fp, name
    nick = 'my-soffle' if lib == PROJ else os.path.basename(lib).replace('.pretty', '')
    fp.SetFPID(pcbnew.LIB_ID(nick, name))
    fp.SetParent(b)
    b.Add(fp)
    fp.SetPosition(pcbnew.VECTOR2I(F(x), F(y)))
    if rot:
        fp.SetOrientationDegrees(rot)
    if flip:
        fp.Flip(fp.GetPosition(), pcbnew.FLIP_DIRECTION_LEFT_RIGHT)
    fp.SetReference(ref)
    fp.Reference().SetVisible(False)
    fp.SetAttributes(fp.GetAttributes() | pcbnew.FP_BOARD_ONLY | pcbnew.FP_EXCLUDE_FROM_POS_FILES | pcbnew.FP_EXCLUDE_FROM_BOM)
    print(ref, name, 'at', x, y, 'bottom' if flip else 'top')


def main():
    b = pcbnew.LoadBoard(sys.argv[1])
    for part in PARTS:
        add_part(b, *part)
    # The pours would flood the rails and tabs, leaving exposed copper and burrs where they snap, so keep every layer
    # clear there: a band over each rail (both sit clear of the board, so no pour inside the board is touched) and one
    # rectangle per tab, reaching 0.1 mm into the board edge.
    KEEPOUTS = [('rail top keepout', 49.0, 50.0, 318.0, 56.0), ('rail bottom keepout', 49.0, 178.25, 318.0, 184.25)]
    for x, edge in ((77.0, 62.0), (113.0, 57.12), (149.0, 61.38), (218.0, 61.38), (254.0, 57.12), (290.0, 62.0)):
        KEEPOUTS.append(('tab keepout x%g' % x, x - 2.6, 55.4, x + 2.6, edge + 0.1))
    for x in (95.0, 135.0, 232.0, 272.0):
        KEEPOUTS.append(('tab keepout x%g' % x, x - 2.6, 170.325, x + 2.6, 178.85))
    for name, x0, y0, x1, y1 in KEEPOUTS:
        z = pcbnew.ZONE(b)
        z.SetIsRuleArea(True)
        z.SetDoNotAllowZoneFills(True)   # KiCad 10 name for "keep out copper pours"
        z.SetDoNotAllowTracks(True)
        z.SetDoNotAllowVias(True)
        z.SetDoNotAllowPads(False)          # the tooling hole and fiducial live here
        z.SetDoNotAllowFootprints(False)
        z.SetLayerSet(pcbnew.LSET.AllCuMask())
        z.SetZoneName(name)
        pts = z.Outline()
        pts.NewOutline()
        for x, y in ((x0, y0), (x1, y0), (x1, y1), (x0, y1)):
            pts.Append(F(x), F(y))
        b.Add(z)
        print(name, 'added')

    for z in b.Zones():
        z.UnFill()
    b.Save(sys.argv[1])


if __name__ == '__main__':
    main()

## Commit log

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2026-09-13 feat(schematic): fix RP2040 controller and add the full keyboard half
    Fixes the controller defects that would have stopped the board working and adds the matrix, LEDs, encoders and display support, audited against the RP2040 datasheet, the RP2040 hardware design guide and each part's datasheet.
    - USB D+/D- now reach the RP2040 through one ESD channel each; QSPI SD0/SD1 no longer swapped; duplicate U1 renamed U5
    - crystal is the reference ABM8-272-T3 with 15 pF load caps; RUN follows the minimal design (no capacitor)
    - Schottky after the fuse stops two hosts back-feeding through the link; GP13 VBUS sense divider sized for the fault-tolerant pin limit
    - 37-key matrix on Keebart's pin map plus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
    [sofle-choc-pro.kicad_sch]
2026-09-13 feat(scripts): add snap_leds.py to place LEDs, caps and diodes from switches
    Placing 111 small parts by hand is slow and error prone, so the script positions each key's LED, decoupling cap and diode relative to its switch.
    - follows switch rotation and puts all three parts on the back side
    - offsets were DRC-checked on plain keys, combo keys and rotated keys
    - runs from the pcbnew scripting console or KiCad's Python on a closed board
    [snap_leds.py]
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2026-09-13 feat(scripts): place footprints from Ergogen and render keycap previews
    Placing 148 key-area footprints by hand is slow and easy to get wrong, so a script moves them onto Ergogen's points and a preview shows keycap and knob fit before touching KiCad.
    - place_from_ergogen.py positions each SWnn by reference with its LED side, snaps LEDs, caps and diodes, and replaces Edge.Cuts with the Ergogen outline
    - render_keycaps.py draws MBK-size keycaps and encoder knobs side by side for both combo options
    - snap_leds.py can be loaded without running, so the placement script reuses its offsets
    [place_from_ergogen.py, render_keycaps.py, snap_leds.py]
2026-09-13 feat(pcb): place the key area from Ergogen and adopt its outline
    The board now carries the Ergogen layout, so routing and controller placement can start from the real key positions.
    - all 37 switches on their Ergogen points with the per-key LED side; 111 LEDs, caps and diodes snapped to them
    - Edge.Cuts replaced by the Ergogen outline; GND pour refilled
    - 37 LED footprints updated in place to the 0.55 mm cutout clearance, keeping their schematic links and fields
    - C21 removed to match the schematic; DRC schematic parity reports 0 issues
    [sofle-choc-pro.kicad_pcb]
2026-09-13 feat(templates): add placed rp2040 inner-column module template
    A reusable KiCad template for the onboard RP2040 controller, cut from the
    audited Sofle schematic and placed on the 19.56 x 41.6 mm inner-column strip
    like the Keebart board. Parts are placed for hand routing, not routed.
    - Drop-in controller: all 30 GPIOs exposed as labels, LCSC parts matching the keyboard
    - DRC-clean placement: 0 parity issues, no courtyard, clearance or silkscreen problems
    - Critical parts tight to their pins: 1V1 caps 1.4 mm, flash facing the QSPI side
    - JLC order-number marker below the RP2040, reference designators kept on B.Fab
    - Reproducible: scripts/build_rp2040_module.py rebuilds the placement from th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
    [RP2040InnerColumn.kicad_pcb, RP2040InnerColumn.kicad_sch]
2026-09-13 fix(templates): re-place rp2040 module at 45 degrees so it can be routed
    The first placement passed DRC but could not be routed: parts sat 0.26 mm
    apart and crowded the RP2040 pins. The module is re-placed with routing room
    and checked by autorouting instead of DRC alone.
    - Routable: the only variant Freerouting routed 100% on 2 layers, confirmed
    in KiCad DRC at 0.15 mm with every signal and power net connected
    - Room to route: 0.6 mm minimum between parts, 1.6 mm fanout ring at U1
    - Short GPIO escapes: RP2040 at 45 degrees faces its GPIO sides toward the
    key area, flash turned to face the QSPI pins
    - Fine-pitch rule: .kicad_dru allows 0.15 mm clearance at U1 and J1 only
    - Net classes r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
    [RP2040InnerColumn.kicad_pcb]
2026-09-13 refactor(templates): split rp2040 module into two groups, drop outline
    The module is pasted into an existing keyboard board, so it no longer carries
    its own Edge.Cuts. Following ScottoModules, the parts now sit in two groups
    that move as units on the host board.
    - Paste-ready: no board outline to delete after copying into a keyboard
    - Two modules: "USB and power" (connector, ESD, fuse, diode, regulator) and
    "RP2040" (MCU, flash, crystal, decoupling, BOOT/RESET, JLC marker)
    - Same placement as before, so the routability check still applies
    - README and template description explain the groups and the expected
    invalid_outline DRC item
    [RP2040InnerColumn.kicad_pcb]
2026-09-13 fix(scripts): keep module project settings when rebuilding the board
    pcbnew's BOARD.Save rewrites the .kicad_pro next to the board with default
    settings, so every rebuild silently deleted the template's net classes.
    - Net classes survive rebuilds: the project file is restored byte for byte
    after saving the board
    [build_rp2040_module.py]
2026-09-13 chore(kicad): move the project and module template to KiCad 10
    KiCad 10 opens the newer ScottoKeebs footprints and the routing and fanout
    plugins that KiCad 8 cannot run. The last KiCad 8 state is tagged
    kicad8-final; KiCad 8 can no longer open these files.
    - Same design: schematics, boards and libraries saved in KiCad 10 formats,
    every footprint position identical to the KiCad 8 tag, 0 ERC errors and
    0 schematic parity issues on both projects
    - Settings kept: project files migrated by KiCad 10 with nothing removed,
    template net classes and patterns intact
    - Module script runs on KiCad 10 Python: GetField replaces GetFieldByName,
    nested library tables and the new netlist layout pars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
    [RP2040InnerColumn.kicad_pcb, RP2040InnerColumn.kicad_sch, sofle-choc-pro.kicad_pcb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]
2026-09-14 feat(templates): route the rp2040 module on 2 layers
    The 135 degree module is now fully routed. KiCad Routing Tools did the QFN
    fanout, GND pour and first pass on a test board; the rest was finished by
    hand in KiCad 10 and copied onto the template.
    - Ready to wire: every GPIO runs out to the strip's left or bottom edge
    - Checked: 0 schematic parity issues, no clearance, via or hole errors
    - Buildable at JLCPCB standard 2-layer limits (0.127 mm clearance and
    track, 0.45/0.2 mm vias); the 0.15 mm fine-pitch rule file is dropped
    as redundant
    - Repeatable copy: scripts/transfer_module_routing.py cuts GPIOs at the
    strip edge and leaves the test pads behind
    - README lists the known leftover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
    [RP2040InnerColumn.kicad_pcb]
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2026-09-14 feat(pcb): place the controller, connectors and diodes on the keyboard
    The Sofle board's own controller parts are placed fresh (not copied from
    the module template), with net classes and a fine-pitch clearance rule so
    it can be routed on 2 layers at JLCPCB standard limits.
    - Controller strip: RP2040 at 45 degrees, host USB-C on the top edge, link
    USB-C on the inner edge above encoder 2, display header on the front
    - Easy to reach: BOOT/RESET above the thumbs where the Keebart board has
    them, solder jumpers spaced for an iron below encoder 1
    - Routing widths: Power5V 0.5 mm (incl. VBUS), Power3.3V 0.3 mm, USB 0.2 mm;
    0.127 mm clearance allowed only at the RP2040 and USB-C connectors
    -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
    [sofle-choc-pro.kicad_pcb]
2026-09-14 feat(pcb): use 2-pin ts-1088 buttons for boot and reset
    BOOT and RESET (SW1, SW2) now use the smaller 2-terminal XUNPU
    TS-1088-AR02016 tactile switch instead of the 4-pin TS-1187A.
    - LCSC C720477 is a JLCPCB Basic part, so no extended-part fee
    - 4 x 3 mm body with one pad per short end, easier to fit and route
    - Footprint and STEP model live in the project library, so the board
    does not depend on the PCM JLCPCB library being installed
    Swapped in place: same position, side, rotation and nets. ERC 0 errors;
    DRC counts did not rise and schematic parity passes.
    [sofle-choc-pro.kicad_pcb, sofle-choc-pro.kicad_sch]
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2026-09-14 feat(sch): protect the link port and harden master detection
    The link USB-C port could back-feed 5 V into a misplugged device and its
    data line had no current limit, and diode leakage could fool the VBUS
    divider on the secondary half. These fixes follow the reference boards
    with a real USB-C link (Djinn, YAEMK) and Splinky's detect divider.
    - F2 polyfuse (same part as F1) between J2 VBUS and +5V; the connector
    side is now LINK_VBUS, and J2 CC stays open so hosts keep VBUS off
    - R16 120 ohm between J2/U2 and GP12 (net LINK_DATA on the connector
    side) limits ESD clamp current and damps cable ringing
    - R10/R11 now 5.1k/10k (was 10k/15k): same 3.3 V at GP13 with a stiffer
    divider against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
    [sofle-choc-pro.kicad_pcb, sofle-choc-pro.kicad_sch]
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2026-09-15 feat(pcb): swap row and column pins and clear u1's trunk side
    Rows now leave U1 on the west-facing pins and columns on the north-west
    pins, so each group heads straight for its corridor. A few parts moved
    off U1's matrix side for the same reason.
    - Rows 1-6 on GP23-GP18 (pins 35-29), columns 0-5 on GP29-GP24
    (pins 41-36); the encoder-key column stays on GP5
    - R10/R11 moved next to GP13, C13/C14 off the west and north-west pins,
    F1 moved clear of the F.Cu trunk corridor left of the strip
    ERC 0 errors; DRC with schematic parity shows only unconnected items
    and starved thermals (the board is still unrouted).
    [sofle-choc-pro.kicad_pcb, sofle-choc-pro.kicad_sch]
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2026-09-15 feat(pcb): move to 4 layers with planes, wson flash and usb pairs
    Applies the accepted v5e controller placement and turns the board into a
    4-layer design, so the controller strip has room to be hand routed and the
    USB lines get a proper reference.
    - U1 straight at 180 degrees and 4 mm lower, every signal pin keeping a
    3.5 mm escape lane; caps, crystal and flash follow the RP2040 Community
    Edition controllers
    - 16 MB flash swapped to the WSON W25Q128JVPIQ (LCSC C190862), which halves
    the QSPI run to 25.7 mm
    - inner GND and +5V planes with a +3.3V island under the controller, and no
    plane under the crystal
    - USB data renamed into real pairs (D_USB, USB_MCU, LINK_D) with a rule that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
    [sofle-choc-pro.kicad_pcb, sofle-choc-pro.kicad_sch]
2026-09-16 feat(pcb): swap usb-c and esd parts, fix nets, rules and silkscreen
    Moves both USB-C ports to the part every reference board uses, shrinks the
    ESD arrays and cleans up the nets, rules and silkscreen around them. The
    board passes ERC and DRC with no errors and no schematic parity issues.
    - USB-C J1/J2 are now HRO TYPE-C-31-M-12 (LCSC C165948), the connector the
    RP2040 design guide, Corne v4, Djinn, Ferris and sea-picro all use, with
    its real 3D model and a project footprint whose pad numbers match our
    symbol; both sit 0.49 mm proud of the board edge, per its datasheet
    - ESD arrays are USBLC6-2P6 in SOT-563 (2.0 x 2.5 mm against 3.1 x 2.1),
    and their two channels now carry each data l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
    [sofle-choc-pro.kicad_pcb, sofle-choc-pro.kicad_sch]
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2026-09-16 fix(pcb): drop the dead link d- pad and exempt the esd fan-out
    The link between halves is one-wire serial, so D- stops at the ESD array.
    Both of its pads carried the net, which left KiCad asking for copper between
    two pins the chip already joins inside. Now only the pad the connector
    reaches is wired, and the other is a no-connect.
    - U2 pin 3 disconnected in the schematic and on the board: four fewer
    unconnected items, and no more phantom pad-to-pad link
    - D+/D- spacing rule now skips U4's courtyard as well as J1's and U1's,
    since the ESD array's two data pins sit 2.3 mm apart and set the gap
    Also carries the USB and link routing done in KiCad since the last commit.
    ERC 0 errors. DRC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
    [sofle-choc-pro.kicad_pcb, sofle-choc-pro.kicad_sch]
2026-09-16 feat(pcb): apply jlcpcb 4-layer rules and fix ground pours
    Sets the board to JLCPCB's recommended 4-layer values and fixes the ground
    pours that left SMD grounds unconnected. Also carries the routing done by
    hand in KiCad since the last commit.
    - stackup defined as JLC04161H-7628 (the board had none, so KiCad guessed)
    - constraints at JLCPCB's recommended values: hole to track 0.35 mm, via
    annular ring 0.15 mm, via diameter 0.45 mm (smaller costs extra), silk to
    pad 0.15 mm (closer is deleted at their review)
    - pre-defined sizes: tracks 0.127/0.2/0.3/0.5 mm, vias 0.7/0.3 (their
    recommended ring), 0.6/0.3 and 0.8/0.4, pair 0.2/0.2; teardrops on
    - ground pours connect SMD pads solidly a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
    [sofle-choc-pro.kicad_pcb]
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2026-09-17 feat(pcb): reroute the key matrix and start the usb pairs
    The old routing is cleared and the key area is routed again with the
    ribbon router, leaving the controller area open for hand routing.
    - Every switch-to-diode link, row, column and LED data link in the key
    area is routed along the key outlines
    - Each LED has a 0.3 mm trace to its cap and a via to the +5V plane
    - Each LED cap has a GND via to the plane, so no ground pour islands
    - Hand-routed D+/D- from J1 to U4 and the link pair from J2 to U2, with
    the connector pins bridged and lengths matched
    - Project adds a 0.25 mm track width and new zone defaults
    DRC: 0 errors; the remaining unconnected items are controller links
    (rows and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
    [sofle-choc-pro.kicad_pcb]
2026-09-17 feat(pcb): route the host usb pair to the resistors
    D+/D- now run from J1 through U4 to R7/R8, matched to within 0.06 mm,
    and the skew rule no longer counts J1's pin-swap bridges.
    - J1 to U4 leaves the connector pads straight down at 0.5 mm pitch
    - U4 to R7/R8 routed as a pair with a 0.2 mm gap, no vias
    - The D pair skew check skips the J1 courtyard: the bridges are stubs
    the signal never runs through, but KiCad counted them and reported a
    false 0.12 mm skew
    DRC: 0 errors. Still open: U4 pin 6 to 1 and 4 to 3 under the chip,
    R7/R8 to U1, and leftover track fragments for Tools > Cleanup Tracks.
    [sofle-choc-pro.kicad_pcb]
2026-09-18 feat(pcb): route the controller area by hand
    Work in progress on the controller strip: the matrix trunks now reach
    U1, and the flash, crystal, display and USB sections are routed.
    - Matrix rows GP18-23 and columns GP24-29 land on U1
    - USB_P/USB_N join R7/R8 to U1, both 3.20 mm
    - QSPI flash (CLK, SD0-SD3, SS), crystal and RUN are routed
    - Display lines DISP_SCL/DISP_SDA reach J3
    - Encoder pins GP3-GP8, +3.3V, +1V1 and LINK_VBUS are routed
    - 590 more track segments and 94 more vias than the last commit
    DRC: 24 clearance errors left, all in this area: matrix trunks crowding
    each other west of U1, the flash lines around CLK and SD0, +1V1 by C16,
    and GP7/GP8 by C11. 28 unconnected items remain.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
    [sofle-choc-pro.kicad_pcb]
2026-09-18 feat(pcb): rework the rp2040 area for hand routing
    Routing is cleared for a fresh start, and the RP2040's power now escapes
    inward under the chip the way Raspberry Pi's own minimal board does, so
    the outside of the pad ring is left for signals.
    - Fixes 38 pads that had drifted to +5V against the schematic: the GND
    pad of every LED cap (C110-C165) and U4's GND pin
    - Adds a +3V3 ring and a +1V1 C-ring as B.Cu zones between the exposed
    pad and the pins, with four corner vias to the In1 +3.3V island
    - Moves C3, C10-C13 and C15 out of the flash, matrix and encoder escapes
    - Shrinks the In1 +3.3V island to the U1 and flash block so every +5V pin
    can drop to the +5V plane instead of running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
    [sofle-choc-pro.kicad_pcb]
2026-09-18 feat(pcb): route +3.3v and +1v1 around the rp2040
    Every 3.3 V and 1.1 V cap near the RP2040 is now wired in with short
    0.2 mm tracks, and each 3.3 V cap has its own via to the In1 plane.
    - Pin 45 feeds C8, pin 23 feeds C5 and C6; the +1V1 ring joins pin 50
    - Pins 42/43 feed C14, C17 and C7; pin 49 feeds C16, the only way
    pins 48/49 reach +3.3V
    - C3 ties the flash to +3.3V; C10-C15 each drop to the plane
    - The LDO side (U5, C9, C19, R12, R13) reaches the plane through a new
    In1 +3.3V strip down the west edge, and J3 pin 3 is fed from R13
    - C6 moves beside C5 under pin 23, C10 turns 180 degrees and C19 moves
    next to U5 so each via has room
    DRC: 0 errors, parity 0. Still open: JP1's +3.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
    [sofle-choc-pro.kicad_pcb]
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2026-09-18 feat(pcb): route all power through the inner planes
    Every power and ground pad is now connected, through a short stub to a
    via beside the pad into the In1 and In2 planes, so the outer layers stay
    free for signals.
    - USB pair joined through U4: U2 and U4 use a project SOT-563 footprint
    that declares pins 1/6 and 3/4 as bonded, as ST's USBLC6-2 datasheet
    routes them, so D+/D- flow through the package
    - VBUS runs 0.5 mm straight from J1 to F1; the D1 to U4 +5V trunk that
    blocked it is gone, and F1 to D1 widens to 0.5 mm
    - +5V vias at D1/C18, U4, U2, U5, C20, F2, U6/C30 and every LED; each LED
    cap also gets a GND stitching via
    - LINK_VBUS runs from J2 to F2, J2's two VBUS pads joined by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
    [sofle-choc-pro.kicad_pcb, sofle-choc-pro.kicad_sch]
2026-09-18 fix(pcb): keep the flash lines over one reference plane
    SD1 and SD2 cross under U3 on F.Cu out to x 177.5, but the In1 +3.3V
    island stopped at x 175.4, so their reference plane split into +5V
    there. The island now reaches x 178.2 under U3.
    - SD1/SD2 run over +3.3V the whole way; the +5V plane stays one piece
    - Removes a duplicated +3.3V segment between R13 and R12
    - Includes the hand routing of GP12, GP13, the crystal net and SD1
    Checks: DRC 0 errors, parity 0; nothing unconnected on power or GND.
    [sofle-choc-pro.kicad_pcb]
2026-09-19 feat(pcb): route the key matrix and tidy the controller fixes
    Most of the key matrix is now routed by hand, and four issues from the
    last check are fixed so the board stays DRC-clean.
    - Rows GP18-GP23, columns GP24-GP29, the switch-to-diode links and part
    of the LED data chain are routed
    - R4 sits where the boot-button line leaves SS, so SS is 15.8 mm and the
    long run to SW1 is behind the 1k on its own net
    - The crystal keep-out follows X1's new spot; the +3.3V strip from U5
    goes round the west of the crystal instead of under it
    - GP18 by SW16 and GP23 by SW25 clear the 0.2 mm key-area rule
    Checks: DRC 0 errors, parity 0, ERC 0; nothing unconnected on power or
    GND. 60 signal items le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
    [sofle-choc-pro.kicad_pcb]
2026-09-19 feat(ergogen): follow the user's thumb cluster moves
    SW63, SW64 and SW65 were moved in KiCad to match Keebart's thumb
    cluster; Ergogen now places them there and the board follows it.
    - thumb3, thumb4 and encoder1 anchors match the board; SW65 stays on
    x 168.00 so the encoder column and right edge stay straight
    - The three fitted outline points are recomputed (bottom edge 0.65 mm
    higher, right edge runs 3 mm further down before turning along TH4)
    - Their LEDs, caps and diodes are re-snapped, with attached copper moved
    along; GP18, GP25 and the D64/D65 links reroute around the moved
    holes, and LED64's +5V via follows it
    Checks: DRC 0 errors, parity 0, ERC 0; all 37 switches on Ergoge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
    [sofle-choc-pro.kicad_pcb]
2026-09-19 feat(pcb): route more of the led data chain by hand
    Hand-routed LED data links and small touch-ups since the thumb cluster
    commit. Open connections drop from 43 to 38.
    - LED data chain: LED_D15 to LED_D20, LED_D23 to LED_D25, LED_D32 to
    LED_D36 routed
    - Touch-ups on GP18, GP19, GP21, the USB pair, +1V1 and a few power stubs
    DRC: 0 violations, 0 parity issues, 38 unconnected (all signals).
    [sofle-choc-pro.kicad_pcb]
2026-09-19 feat(pcb): start the led chain at the encoders and route columns 4-5
    The LED data chain now runs R15, LED16, LED65, the thumbs, column 5 up
    and column 4 down, so it no longer detours across column 5 to reach the
    upper encoder. Columns 4 and 5 are routed by hand on the new order.
    - Chain order picked by scoring every order on pad-to-pad length and
    crossings: 663 mm instead of 719 mm, no hop crosses a foreign key
    cell except LED63 to LED55 around SW2
    - Only LED_D0 to LED_D8 were reassigned (9 LEDs); the routed tail from
    LED62 on is unchanged
    - LED_D3 to LED_D14 routed, plus reworked GP22, GP24 and matrix nets
    ERC: 0 errors. DRC: 0 errors, 0 parity, 29 unconnected. Known issues
    to fix n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
    [sofle-choc-pro.kicad_pcb, sofle-choc-pro.kicad_sch]
2026-09-19 fix(pcb): reconnect led grounds and pull data vias off their pads
    The column-5 LED data routes had sealed the GND pads of LED35, LED45 and
    LED55 into pour pockets with no way to ground. Each now has its own via,
    and the data vias that touched their pads sit beside them instead.
    - GND via (0.6/0.3) with a 0.3 mm B.Cu stub beside LED35, LED45, LED55
    - 11 LED data vias slid to a 0.3 mm gap from their pads (LED_D7-D9,
    LED_D11-D14, LED_D22-D25); attached track ends follow
    - Removed the dangling GP22 via at (142.4, 82.15) and three
    zero-length segments (GP24, VBUS)
    Left as is: the LED_D10 via at LED24 (0.04 mm gap), boxed in by the
    B.Cu matrix ribbon, LED24's cutout and SW24's hole.
    ERC: 0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
    [sofle-choc-pro.kicad_pcb]
2026-09-19 feat(pcb): route crystal, display, link and more of the led chain
    Hand routing snapshot before the stuck nets and the clean-up round the
    lower half of U1. Committed as is so the clean-up has a restore point.
    - Crystal, display (DISP_SCL/SDA), link, CC2, RUN and most GPIO nets
    routed by hand
    - Open connections down from 26 to 13
    DRC at this commit: 6 clearance errors (+3.3V to DISP_SCL 0.16 mm,
    XTAL_OUT to C6, GP14 to GP15 and R11, all under 0.15 mm), 5 GND pour
    pieces not tied in, and 8 signal connections open: GP2, GP3, GP4, GP5,
    GP7, GP8, GP10, LED_D1.
    [sofle-choc-pro.kicad_pcb]
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2026-09-19 fix(pcb): mirror J3 for the OLED module and clear the silkscreen
    J3 now matches the 0.91 inch OLED module soldered face up and running
    north: west to east it reads SDA, SCL, VCC, GND, like the module's own
    header (JLCPCB C5248081, splitkb, Keycapsss). The old order would have
    powered the module backwards.
    - J3 1x04 rotated 180 degrees; SDA (GP6) and SCL (GP7) re-routed to its
    west pins under J3, +3.3V island reshaped round the new VCC pin
    - R12/R13 removed: the module carries its own 4.7k I2C pull-ups
    - Plate display opening centred on the module and clearing the glass
    by 0.5 mm (3.0 to 34.0 mm past the pins); key points unchanged
    - Reference designators hidden on the silkscreen; outlin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
    [sofle-choc-pro.kicad_pcb, sofle-choc-pro.kicad_sch]
2026-09-19 fix(pcb): prepare the left half for jlcpcb assembly
    Fixes the VBUS sense divider and sets every fabrication field the
    Fabrication Toolkit plugin needs, then commits its JLCPCB outputs.
    - R10 is now 10k like R11: GP9 sees 2.2 to 2.75 V over 4.4 to 5.5 V
    VBUS, inside the RP2040's 2.0 V to IOVDD + 0.3 V input window (the
    old 5.1k gave 3.64 V at 5.5 V)
    - FT Rotation Offset 270 on U2, U3, U4 and 180 on U6, found by fitting
    JLC's own footprints onto ours
    - FT Position Offset 0,1.394 on J1/J2, measured through the locating
    pegs of JLC's C165948 footprint
    - Hotswap sockets, J3 and JP1 leave the position file; the 72 socket
    pads lose their paste on the board and in the library footprints
    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
    [bom.csv, designators.csv, positions.csv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]
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
